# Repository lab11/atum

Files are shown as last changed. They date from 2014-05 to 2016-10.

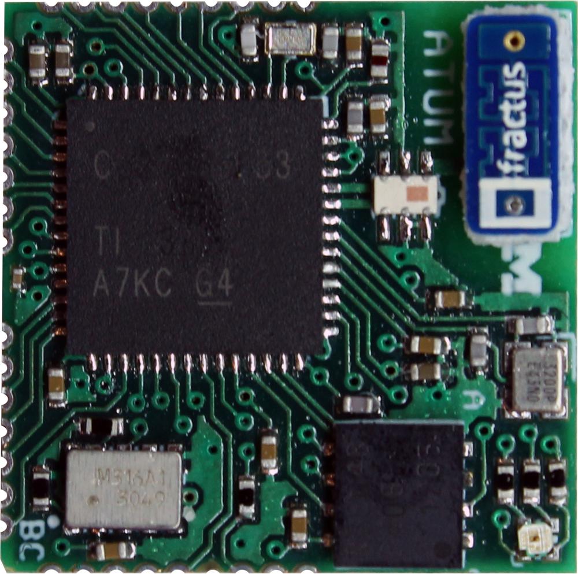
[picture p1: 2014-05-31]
hardware/atum/rev_a/atum.jpg

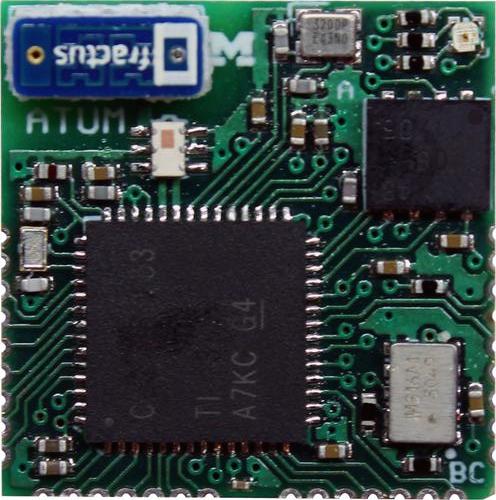
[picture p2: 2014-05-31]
media/atum_a_500x496.jpg

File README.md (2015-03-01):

Atum
====

atum_pcb

Atum is a ½ inch² drop-in sensor node module designed to enable rapid
prototyping of wireless embedded devices. The core of Atum is a CC2538
SoC with an Arm Cortex M3 and 802.15.4 radio. Atum also includes an
antenna, 512 bytes of non-volatile FRAM memory, an RTC, and a tri-color LED.

Atum is designed to have two different usage patterns. First, three sides
of the device have castellated headers allowing Atum to be directly
soldered onto a carrier PCB. Atum handles all of the computation and
communication while the carrier board supplies power and attaches
sensors or other peripherals. In the second option, Atum can function
as a complete sensor node. On the bottom are pads for a 3.3 V regulator
and a battery. If needed, a peripheral or sensor board can be stacked on
top using the headers as a bridge.

History
-------

Atum is the spiritual successor to
[Epic](http://www.cs.berkeley.edu/~prabal/projects/epic/). It is slightly
smaller, replaces flash with FRAM, adds an RTC, and includes an antenna.
Epic was designed to be highly flexible while still providing the
components that are common on many sensor platforms. In practice, however,
I noticed that only a small subset of the common features were regularly
used and that Epic carrier boards often repeated the same designs. Atum
tries to address this by providing a simplified interface that provides
the features (e.g. SPI, I2C, ADC, GPIO) that sensor boards need.

Name
----

The spelling "Atum" is taken from the ancient Egyptian god of creation,
but finds better connections as a misspelling of "atom", a core building
block of matter, and as the conjoined words "at" and "UM", as Atum
was developed at the University of Michigan.

Usage
-----

The [Contiki](https://github.com/contiki-os/contiki) operating system
supports the CC2538 and this repository contains a Contiki platform
for Atum. The Contiki platform provides drivers for the peripherals
on Atum and their wiring to the CC2538. See `CONTIKI.md` for more info.

PCB
---

Atum is currently pannelized 40 to a panel. They are designed to be 1mm thick
with castellations on the edge. See `hardware/atum` for board files and
gerbers.

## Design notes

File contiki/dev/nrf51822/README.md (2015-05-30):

Really basic support for the nRF51822 over spi
==============================================

This is a first pass at defining a SPI interface for the nRF51822 and accessing
it from Atum.

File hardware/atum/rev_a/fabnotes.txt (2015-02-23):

PCB NAME : ATUM
REVISION: A
DATE: 2015-02-23

PCB DESCRIPTION:4 LAYER PCB 1.0 MM
      Copper        1    1.4 mil (1 oz)
      Dielectric  1-2    5.7 mil (e.g. 2x Prepreg 1080)
      Copper        2    1.4 mil (1 oz)
      Dielectric  2-3   22.0 mil
      Copper        3    1.4 mil (1 oz)
      Dielectric  3-4    5.7 mil (e.g. 2x Prepreg 1080)
      Copper        4    1.4 mil (1 oz)
  DE104iML or equivalent substrate (Resin contents around 45%, which gives Er=4.42@2.4GHz, TanD=0.016)
  Dimensions in mil (0.001 inch)
  DOUBLE SIDE SOLDER MASK,
  DOUBLE SIDE SILKSCREEN,
  6 MIL MIN TRACE WIDTH AND 6 MIL MIN ISOLATION.

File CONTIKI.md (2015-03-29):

Programming Atum
================

The software for Atum is currently based on the Contiki support for
the TI CC2538. Getting running is pretty straightforward.

1. You need the `arm-none-gnueabi-gcc` compiler from
[here](https://launchpad.net/gcc-arm-embedded).

2. Clone Contiki recursively.

        git clone --recursive https://github.com/contiki-os/contiki.git

    Cloning recursively also pulls in the BSL programming script that loads
    code on the CC2538.

3. Now you should be able to build the blink app.

        cd contiki/apps/blink
        make

    You need to make sure that `CONTIKI` in the Makefile points to where
    you cloned the Contiki repository.

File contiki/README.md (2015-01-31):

Atum - Contiki
==============

This folder contains code to make Atum a
[Contiki](https://github.com/contiki-os/contiki) platform. Contiki has active
support of the CC2538 and this platform adds on drivers for the FRAM and
RTC chips.

Installation
------------

To compile apps for Atum you need this repository, the main Contiki repository,
and the toolchain.

1. Install the compilers. See
[this](https://github.com/contiki-os/contiki/tree/master/platform/cc2538dk#install-a-toolchain)
for a link to the best compiler to use for the CC2538.
Note: You MUST install from the launchpad website, NOT mentor.

2. Clone the main contiki repository

        git clone https://github.com/contiki-os/contiki.git

3. Add the `/tools` directory in this folder to your path. This folder contains
a script for initializing the RTC with the current time. Something like:

        export PATH=$PATH:$HOME/git/atum/contiki/tools

4. Make sure the applications know where the main Contiki repository is.
Edit `apps/blink/Makefile` and make sure that `CONTIKI = ../../../../contiki`
actually points to where you cloned the Contiki repository.

Compiling an Application
------------------------

At this point compiling a Contiki application for atum
should be very straightforward.

    cd apps/blink
    make

If you wanted to use a different platform (say the CC2538 evm with the SmartRF06
board):

    make TARGET=cc2538dk

Loading the Application to Atum
-------------------------------

Assuming you are using the serial bootloader (pins GND, VCC, !RESET,
BOOTLOADER_CTRL, BOOTLOADER_TX, and BOOTLOADER_RX) you can use the wonderful
[BSL script from JelmerT](https://github.com/JelmerT/cc2538-bsl) by:

    make install

In the case of a permission error for /dev/ttyUSB0, add yourself to the dialout
group.

Errors
------

It's possible these steps will not work. A major reason why is that the CC2538
platform in Contiki is changing rapidly and often adds in new features that
won't compile until the Atum platform is similarly updated. If this happens,
please raise an issue on this repository so that I can fix it.

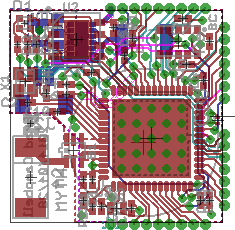
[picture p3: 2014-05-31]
hardware/atum/rev_a/myth_pcb.png

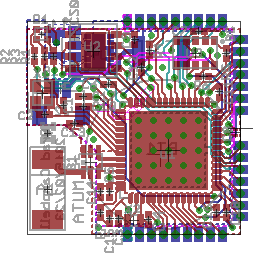
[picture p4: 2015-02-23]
hardware/atum/rev_a/atum_pcb.png

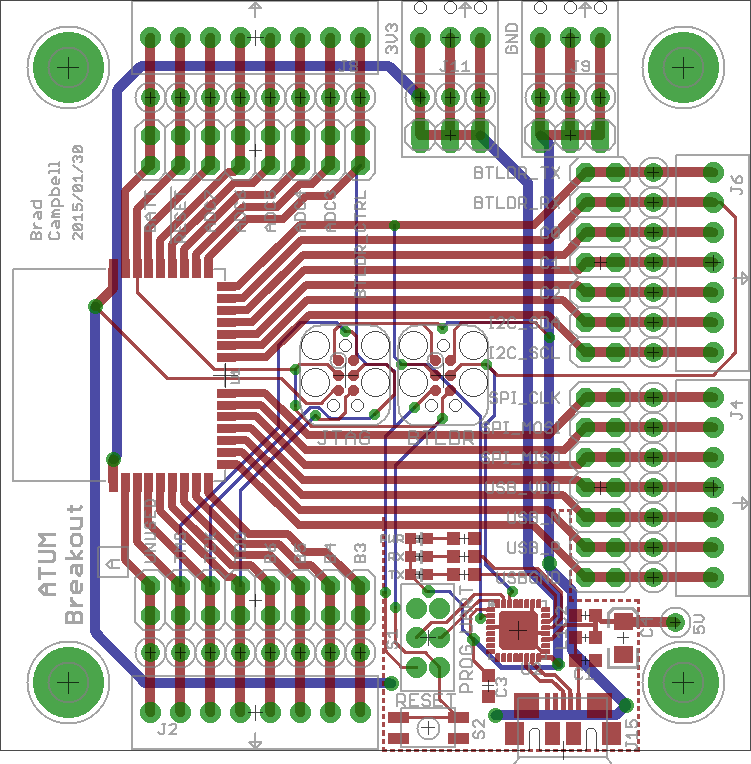
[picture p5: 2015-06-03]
hardware/atum-breakout/rev_a/atum-breakout_pcb.png

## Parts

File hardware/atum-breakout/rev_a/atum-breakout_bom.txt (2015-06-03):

# Bill of Materials
# Converted from atum-breakout_bom.xlsx
# Generated by bom_to_text.py

Qty  Value                          Device                         Package                        Parts                                                               Description                           DIGIKEY        MOUSER              NEWARK
3    0.1u                           C-EUC0603                      C0603                          C1, C2, C3                                                          CAPACITOR, European symbol            445-1316-1-ND  810-C1608X7R1E104K  
1    10u                            CAP_POL1206                    EIA3216                        C4                                                                  Capacitor Polarized                   478-1655-1-ND  581-TAJA106K016R    
1    BLUE                           LED0603                        LED-0603                       D1                                                                  LEDs                                                                     
1    RED                            LED0603                        LED-0603                       D2                                                                  LEDs                                                                     
1    GREEN                          LED0603                        LED-0603                       D3                                                                  LEDs                                                                     
2                                   PINHD-2X8                      2X08                           J1, J7                                                              PIN HEADER                            609-3364-ND    649-68602-116HLF    20M2833
2    SCREW-TERMINAL_8_0.100         SCREW-TERMINAL_8_0.100         CONN_BLOCK_8                   J2, J8                                                              8x 0.100 in screw terminal block      277-1279-ND    651-1725711         71C4111
2                                   PINHD-2X7                      2X07                           J3, J5                                                              PIN HEADER                            609-3491-ND    649-67996-114HLF    30M1973
2    SCREW-TERMINAL_7_0.100         SCREW-TERMINAL_7_0.100         CONN_BLOCK_7                   J4, J6                                                              7x 0.100 in screw terminal block      277-1278-ND    651-1725708         14X4980
2    SCREW-TERMINAL_3_0.100         SCREW-TERMINAL_3_0.100         CONN_BLOCK_3                   J9, J11                                                             3x 0.100 in screw terminal block      277-1274-ND    651-1725669         71C4108
2                                   PINHD-1X3                      1X03                           J10, J12                                                            PIN HEADER                            609-3461-ND    649-68000-103HLF    88K1775
1    MICRO_USB_B_HIROSE_ZX62R-B-5P  MICRO_USB_B_HIROSE_ZX62R-B-5P  USB_MICRO_B-HIROSE-ZX62R-B-5P  J15                                                                 USB Micro B Connector                 H11574CT-ND    798-ZX62R-B-5P      69W0714
1                                   INDUCTOR0603                   L0603                          L1                                                                  Inductors                             240-2373-1-ND  875-MI0603K300R-10  
3    470                            R-US_R0603                     R0603                          R1, R2, R3                                                          RESISTOR, American symbol                                                
1    SSA22/DPDT                     SSA22/DPDT                     SSA22/DPDT                     S1                                                                  SW SLIDE DPDT 2POS SSA SER 30V        450-1604-ND    506-SSA22           50F5561
1    EVQP2                          EVQP2                          EVQP2                          S2                                                                                                        P11084SCT-ND   667-EVQ-P2K02Q      
3    White                          TEST_POINT_0.040IN             TESTPOINT_0.040IN              TP1, TP29, TP30                                                     0.040in Test Point                    5002K-ND       534-5001            
10   Orange                         TEST_POINT_0.040IN             TESTPOINT_0.040IN              TP2, TP3, TP4, TP9, TP10, TP11, TP12, TP21, TP22, TP23              0.040in Test Point                    5003K-ND       534-5001            
12   Yellow                         TEST_POINT_0.040IN             TESTPOINT_0.040IN              TP5, TP6, TP7, TP8, TP18, TP19, TP20, TP24, TP25, TP26, TP27, TP28  0.040in Test Point                    5004K-ND       534-5001            
3    Blue                           TEST_POINT_0.040IN             TESTPOINT_0.040IN              TP13, TP14, TP15                                                    0.040in Test Point                    5117K-ND       534-5001            
2    Green                          TEST_POINT_0.040IN             TESTPOINT_0.040IN              TP16, TP17                                                          0.040in Test Point                    5116K-ND       534-5001            
3    Black                          TEST_POINT_0.040IN             TESTPOINT_0.040IN              TP31, TP32, TP33                                                    0.040in Test Point                    5001K-ND       534-5001            
4    Red                            TEST_POINT_0.040IN             TESTPOINT_0.040IN              TP34, TP35, TP36, TP37                                              0.040in Test Point                    5000K-ND       534-5001            
1    ATUM                           ATUM                           ATUM                           U1                                                                  Atum sensorboard prototyping module.                                     
1    FT232RQ                        FT232RQ                        QFN32                          U2                                                                  FTDI USB                              768-1008-1-ND  895-FT232RQ         91K9919

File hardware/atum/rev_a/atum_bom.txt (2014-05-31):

# Bill of Materials
# Converted from atum_bom.xlsx
# Generated by bom_to_text.py

Qty  Value                           Device                          Package                          Parts                             Description                                                   DIGIKEY           MOUSER               NEWARK   RICHARDSON_RFPD
1    FRACTUS-2.4GHZ-FR05-S1-N-0-102  FRACTUS-2.4GHZ-FR05-S1-N-0-102  FRACTUS-ANTENNA-FR05-S1-N-0-102  A1                                Fractus Compact Reach XtendTM chip antenna                                                                    FR05-S1-N-0102B
1    2450BM15A0002                   2450BM15A0002                   2450BM                           B1                                BALUN JTI MATCHED ZIGBEE                                      712-1536-1-ND     609-2450BM15A0002E   41T1684  
1    ML-1220/F1AN                    ML-1220/F1AN                    ML-1220/F1BN                     BT1                               BATTERY LITH 3V RECHARGE PC PINS                              P663-ND           658-ML-1220/F1BN              
2    12pF                            CAPACITOR                       0402_CAP                         C1, C2                            0402 Capacitor                                                445-1236-1-ND                          90R7560  
2    22pF                            CAPACITOR                       0402_CAP                         C3, C4                            0402 Capacitor                                                490-5868-1-ND                          48W5745  
1    220pF                           CAPACITOR                       0402_CAP                         C5                                0402 Capacitor                                                445-1251-1-ND                          55T0065  
1    1nF                             CAPACITOR                       0402_CAP                         C6                                0402 Capacitor                                                445-2651-1-ND                          90R7554  
1    10nF                            CAPACITOR                       0402_CAP                         C7                                0402 Capacitor                                                445-1260-1-ND                          90R7604  
1    0.1uF                           C-EUC0201                       0201_CAP                         C8                                0201 Capacitor                                                445-1796-1-ND                          90R7553  
7    0.1uF                           CAPACITOR                       0402_CAP                         C9, C10, C11, C12, C13, C14, C15  0402 Capacitor                                                445-1265-1-ND                          87R3259  
3    1uF                             CAPACITOR                       0402_CAP                         C16, C17, C18                     0402 Capacitor                                                445-4998-1-ND                          90R7580  
2    10uF                            CAPACITOR0603_CAP               0603_CAP                         C19, C20                          CAP CER 10UF 6.3V 20% X5R 0603                                490-7316-1-ND                                   
1    SML-LX0404SIUPGUSB              SML-LX0404SIUPGUSB              1MM_SQ_4PAD                      D1                                1mm^2 RGB LED                                                 67-2125-1-ND      696-LX0404SIUPGUSB   23T0583  
1    ATUM-HEADER                     ATUM-HEADER                     ATUM-HEADER                      J1                                                                                                                                              
1    SH_MALE_2/1MM                   SH_MALE_2/1MM                   SH-1X2/1MM                       J2                                1.0mm pitch/Disconnectable Crimp style connectors             455-1788-2-ND                          26P0950  
1    2.2uH                           MIPSZ2012D                      MIPSZ201D                        L1                                FDK Multi-layer Power Inductor (Very Small Type)                                                              
3    1k                              RESISTOR                        0402_RES                         R1, R2, R3                        Resistor                                                      RHM1.0KCECT-ND                                  
1    2.2k                            RESISTOR                        0402_RES                         R4                                Resistor                                                      RHM2.2KCECT-ND                                  
2    10k                             RESISTOR                        0402_RES                         R5, R6                            Resistor                                                      RHM10KCECT-ND                                   
1    56k                             RESISTOR                        0402_RES                         R7                                Resistor                                                      RHM56KBHCT-ND                                   
1    CC2538                          CC2538                          S-PVQFN-N56                      U1                                A Powerful System-On-Chip for 2.4-GHz IEEE 802.15.4, 6LoWPAN  296-35797-1-ND    595-CC2538SF53RTQT   87W7713  
1    FM25LBTDFN-8                    FM25LBTDFN-8                    TDFN-8                           U2                                IC FRAM 4KBIT 10MHZ 8SOIC                                     FM25L04B-DGRA-ND  877-FM25L04B-DG               
1    RV-3049-C3                      RV-3049-C3                      MICRO-CRYSTAL-C3                 U3                                Ultra miniature Real-Time-Clock Module                                                               09X0513  
1    TPS62740                        TPS62740                        R-PWSON-12                       U4                                360nA Step Down Converter for Low Power Applications          296-37134-1-ND    595-TPS62740DSST     27X9745  
1    EPSON-FA-128                    EPSON-FA-128                    FA-128                           X1                                MHz RANGE CRYSTAL UNIT                                        SER3800CT-ND      732-FA128-32F20X-K3           
1    ABS05-32.768KHZ-T               ABS05-32.768KHZ-T               ABS05                            X2                                32.768kHz Crystal                                             535-11899-1-ND    815-ABS05-32.768K-T  24W8430

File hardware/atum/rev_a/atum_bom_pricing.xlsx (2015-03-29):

Qty | Value | Device | Package | Parts | Description | DIGIKEY | MOUSER | NEWARK | RICHARDSON_RFPD | Price@Qty1000 | Total@1000
1 | FRACTUS-2.4GHZ-FR05-S1-N-0-102 | FRACTUS-2.4GHZ-FR05-S1-N-0-102 | FRACTUS-ANTENNA-FR05-S1-N-0-102 | A1 | Fractus Compact Reach XtendTM chip antenna |  |  |  | FR05-S1-N-0102B | 0.68 | 680
1 | 2450BM15A0002 | 2450BM15A0002 | 2450BM | B1 | BALUN JTI MATCHED ZIGBEE | 712-1536-1-ND | 609-2450BM15A0002E | 41T1684 |  | 0.2875 | 287.5
1 | ML-1220/F1AN | ML-1220/F1AN | ML-1220/F1BN | BT1 | BATTERY LITH 3V RECHARGE PC PINS | P663-ND | 658-ML-1220/F1BN |  |  |  | 0
2 | 12pF | CAPACITOR | 0402_CAP | C1, C2 | 0402 Capacitor | 445-1236-1-ND |  | 90R7560 |  | 0.013 | 26
2 | 22pF | CAPACITOR | 0402_CAP | C3, C4 | 0402 Capacitor | 490-5868-1-ND |  | 48W5745 |  | 0.01024 | 10.24
1 | 220pF | CAPACITOR | 0402_CAP | C5 | 0402 Capacitor | 445-1251-1-ND |  | 55T0065 |  | 0.0151 | 15.1
1 | 1nF | CAPACITOR | 0402_CAP | C6 | 0402 Capacitor | 445-2651-1-ND |  | 90R7554 |  | 0.0345 | 34.5
1 | 10nF | CAPACITOR | 0402_CAP | C7 | 0402 Capacitor | 445-1260-1-ND |  | 90R7604 |  | 0.013 | 13
1 | 0.1uF | C-EUC0201 | 0201_CAP | C8 | 0201 Capacitor | 445-1796-1-ND |  | 90R7553 |  | 0.0151 | 105.7
7 | 0.1uF | CAPACITOR | 0402_CAP | C9, C10, C11, C12, C13, C14, C15 | 0402 Capacitor | 445-1265-1-ND |  | 87R3259 |  | 0.0133 | 39.9
3 | 1uF | CAPACITOR | 0402_CAP | C16, C17, C18 | 0402 Capacitor | 445-4998-1-ND |  | 90R7580 |  | 0.0169 | 33.8
2 | 10uF | CAPACITOR0603_CAP | 0603_CAP | C19, C20 | CAP CER 10UF 6.3V 20% X5R 0603 | 490-7316-1-ND |  |  |  |  | 0
1 | SML-LX0404SIUPGUSB | SML-LX0404SIUPGUSB | 1MM_SQ_4PAD | D1 | 1mm^2 RGB LED | 67-2125-1-ND | 696-LX0404SIUPGUSB | 23T0583 |  | 0.406 | 406
1 | ATUM-HEADER | ATUM-HEADER | ATUM-HEADER | J1 |  |  |  |  |  |  | 0
1 | SH_MALE_2/1MM | SH_MALE_2/1MM | SH-1X2/1MM | J2 | 1.0mm pitch/Disconnectable Crimp style connectors | 455-1788-2-ND |  | 26P0950 |  |  | 0
1 | 2.2uH | MIPSZ2012D | MIPSZ201D | L1 | FDK Multi-layer Power Inductor (Very Small Type) |  |  |  |  |  | 0
3 | 1k | RESISTOR | 0402_RES | R1, R2, R3 | Resistor | RHM1.0KCECT-ND |  |  |  | 0.00933 | 9.33
1 | 2.2k | RESISTOR | 0402_RES | R4 | Resistor | RHM2.2KCECT-ND |  |  |  | 0.02031 | 40.62
2 | 10k | RESISTOR | 0402_RES | R5, R6 | Resistor | RHM10KCECT-ND |  |  |  | 0.02031 | 20.31
1 | 56k | RESISTOR | 0402_RES | R7 | Resistor | RHM56KBHCT-ND |  |  |  | 0.02684 | 26.84
1 | CC2538 | CC2538 | S-PVQFN-N56 | U1 | A Powerful System-On-Chip for 2.4-GHz IEEE 802.15.4, 6LoWPAN | 296-35797-1-ND | 595-CC2538SF53RTQT | 87W7713 |  | 6.6924 | 6692.4
1 | FM25LBTDFN-8 | FM25LBTDFN-8 | TDFN-8 | U2 | IC FRAM 4KBIT 10MHZ 8SOIC | FM25L04B-DGRA-ND | 877-FM25L04B-DG |  |  | 1.053 | 1053
1 | RV-3049-C3 | RV-3049-C3 | MICRO-CRYSTAL-C3 | U3 | Ultra miniature Real-Time-Clock Module |  |  | 09X0513 |  | 8.42 | 8420
1 | TPS62740 | TPS62740 | R-PWSON-12 | U4 | 360nA Step Down Converter for Low Power Applications | 296-37134-1-ND | 595-TPS62740DSST | 27X9745 |  |  | 0
1 | EPSON-FA-128 | EPSON-FA-128 | FA-128 | X1 | MHz RANGE CRYSTAL UNIT | SER3800CT-ND | 732-FA128-32F20X-K3 |  |  | 0.6 | 600
1 | ABS05-32.768KHZ-T | ABS05-32.768KHZ-T | ABS05 | X2 | 32.768kHz Crystal | 535-11899-1-ND | 815-ABS05-32.768K-T | 24W8430 |  | 1.061 | 0
 |  |  |  |  | PCB |  |  |  |  | 1.5 | 1500
 |  |  |  |  | Assembly |  |  |  |  | 5 | 5000
 |  |  |  |  |  |  |  |  |  |  | 25014.24
 |  |  |  |  |  |  |  |  |  |  | 25.01424

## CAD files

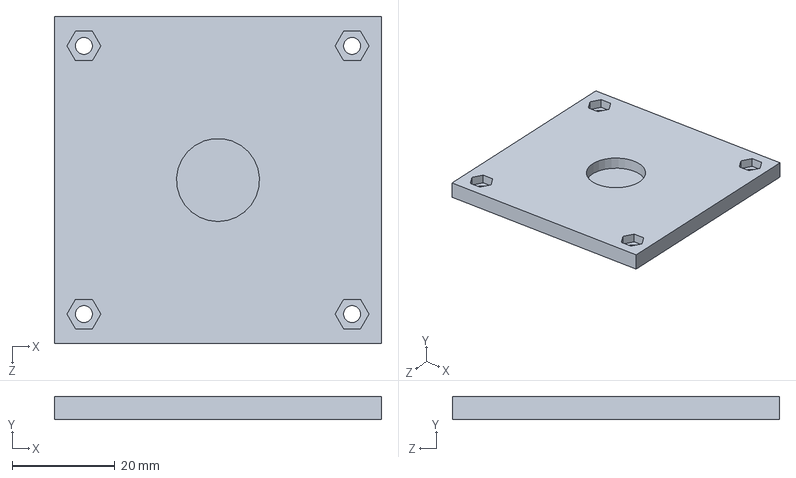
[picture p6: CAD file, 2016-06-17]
3d/atum_breakout_magnet_base.SLDPRT
63.5 x 4.48 x 63.5 mm

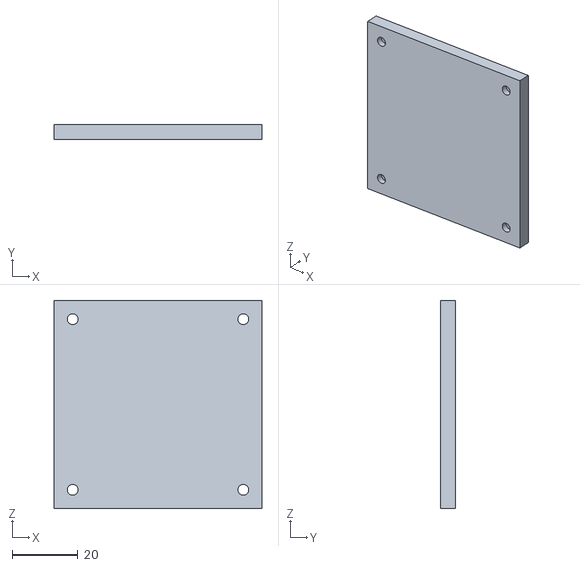
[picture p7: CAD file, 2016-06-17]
3d/atum_breakout_magnet_base_v1.STL
63.5 x 4.48 x 63.5

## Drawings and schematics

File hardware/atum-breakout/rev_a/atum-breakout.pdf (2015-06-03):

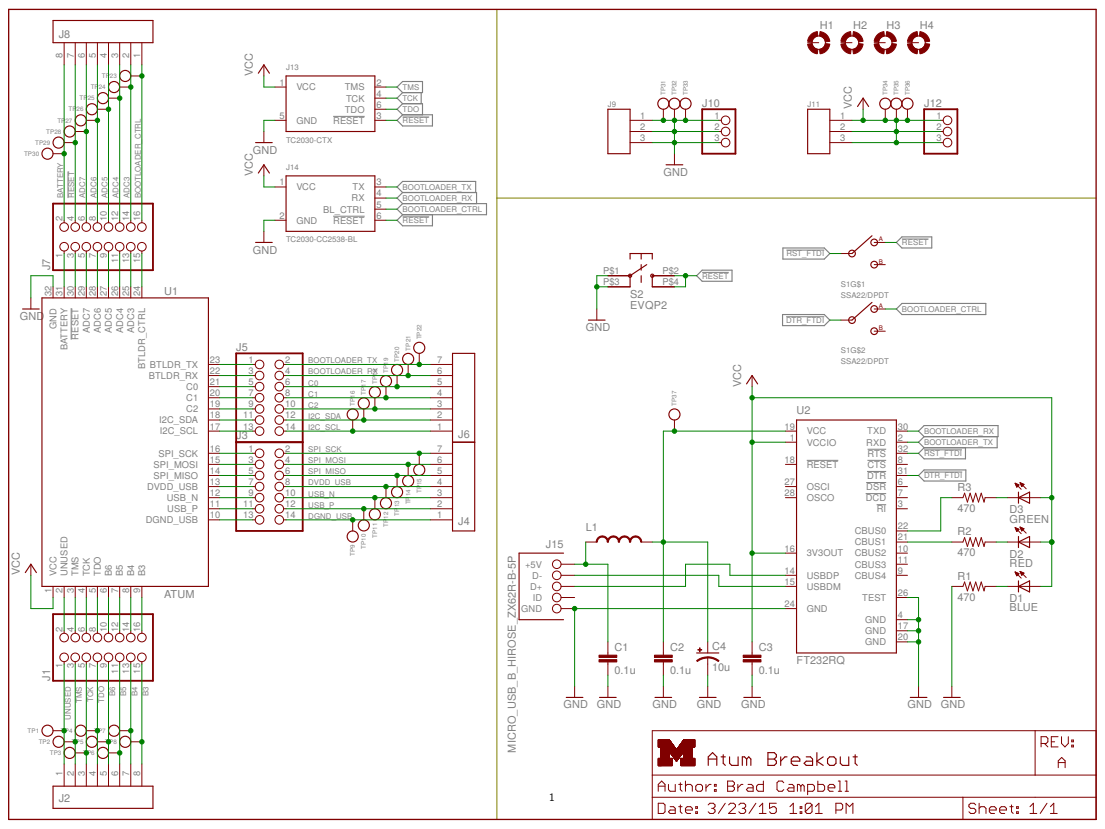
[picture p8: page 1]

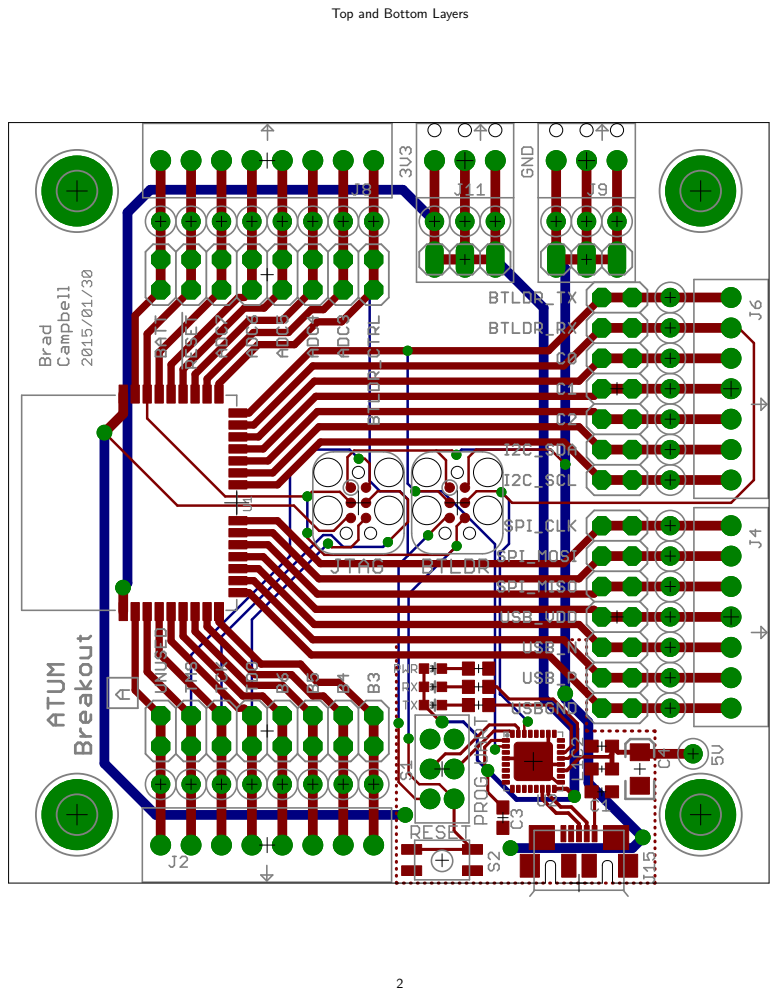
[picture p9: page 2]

Top and Bottom Layers

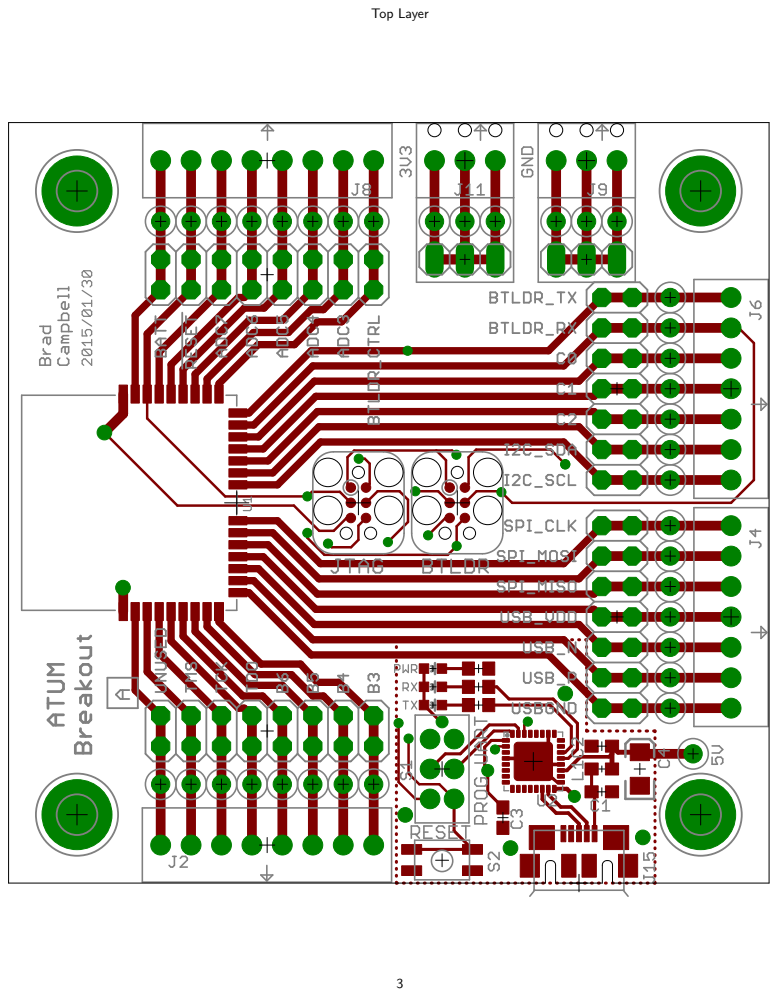
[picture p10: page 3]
Top Layer

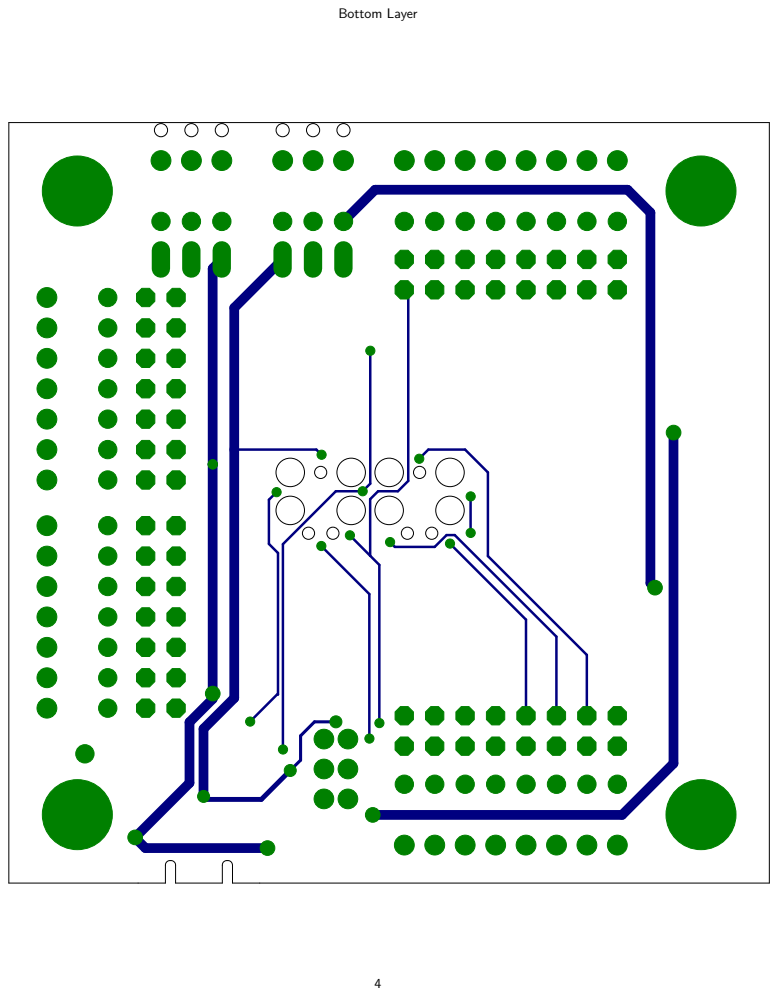
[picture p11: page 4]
Bottom Layer

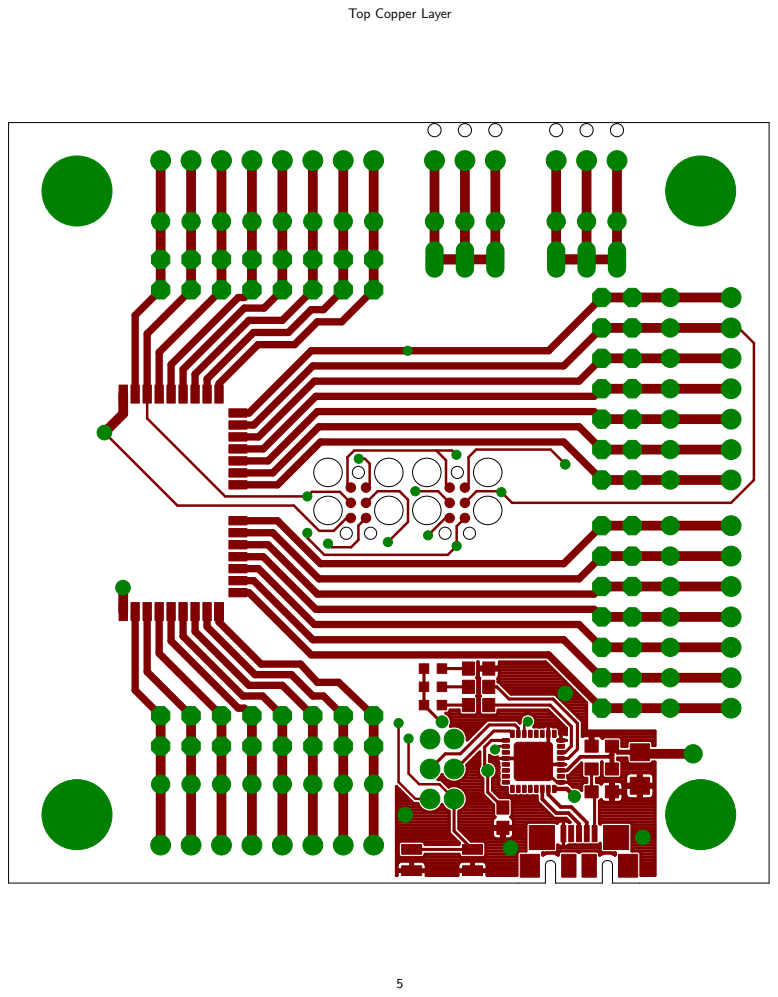
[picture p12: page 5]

Top Copper Layer

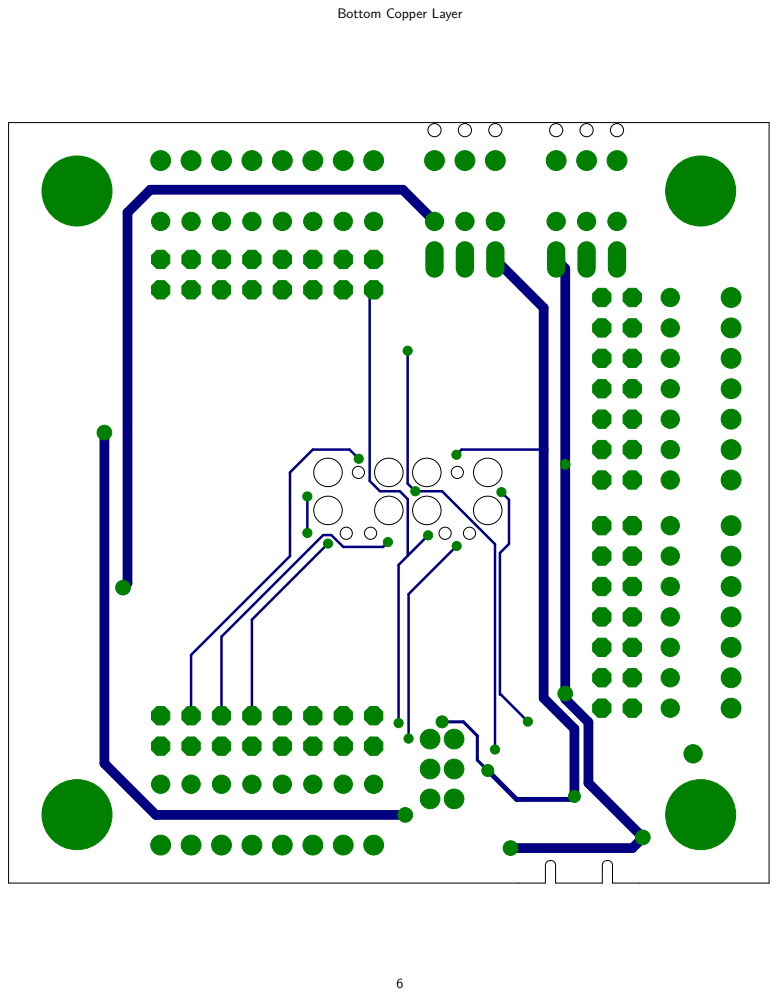
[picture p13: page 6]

Bottom Copper Layer

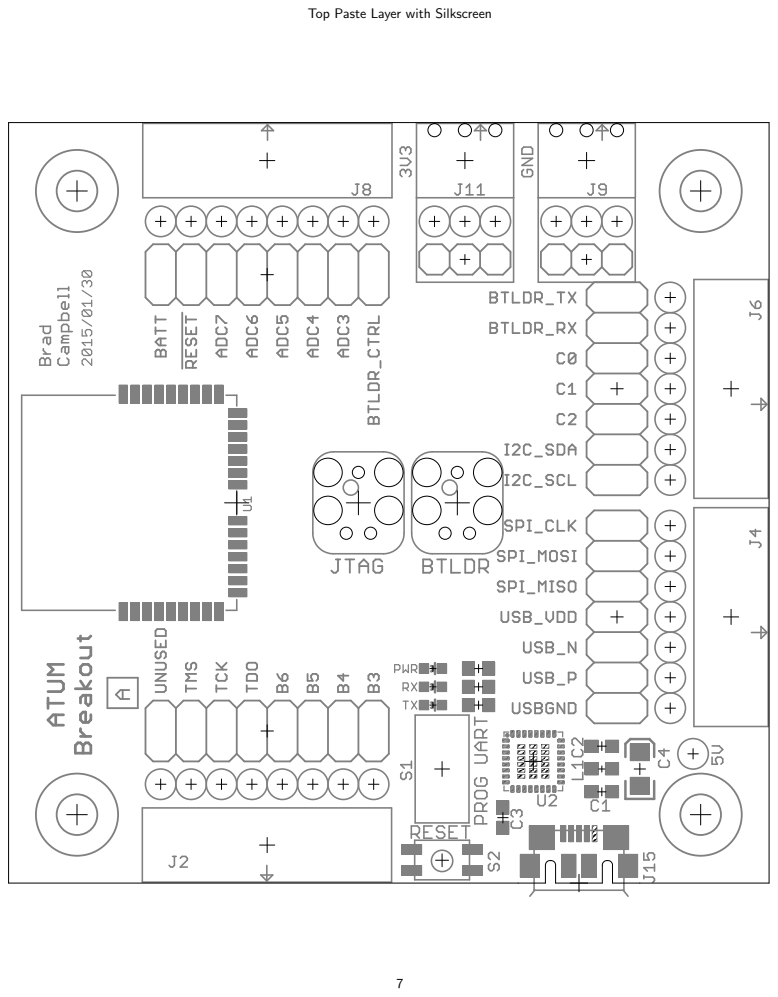
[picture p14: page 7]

Top Paste Layer with Silkscreen

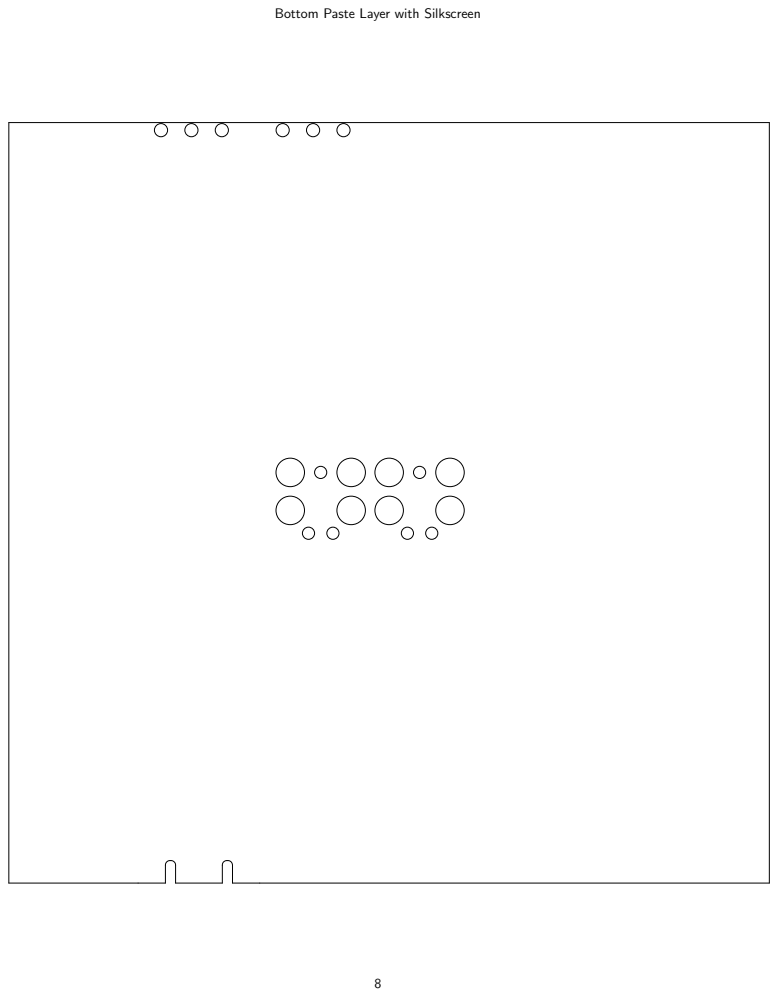
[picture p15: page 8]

Bottom Paste Layer with Silkscreen

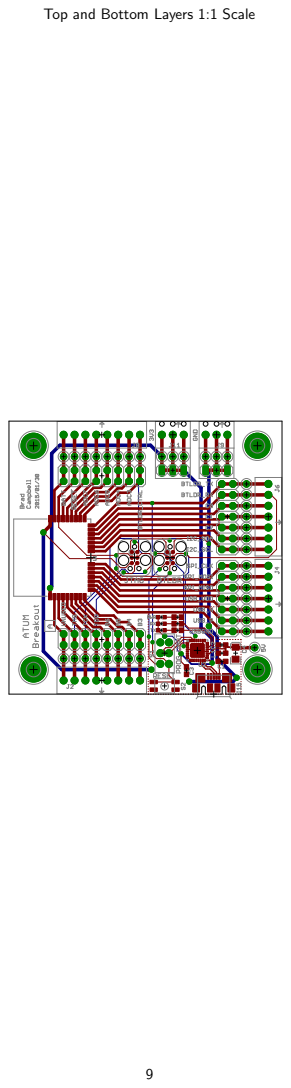
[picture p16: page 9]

Top and Bottom Layers 1:1 Scale

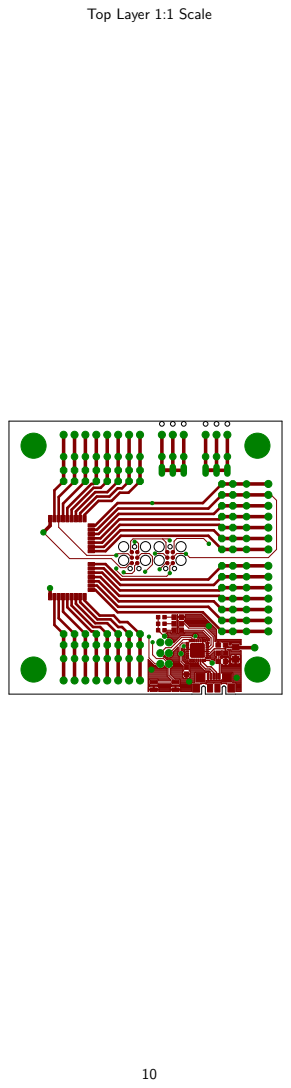
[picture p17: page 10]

Top Layer 1:1 Scale

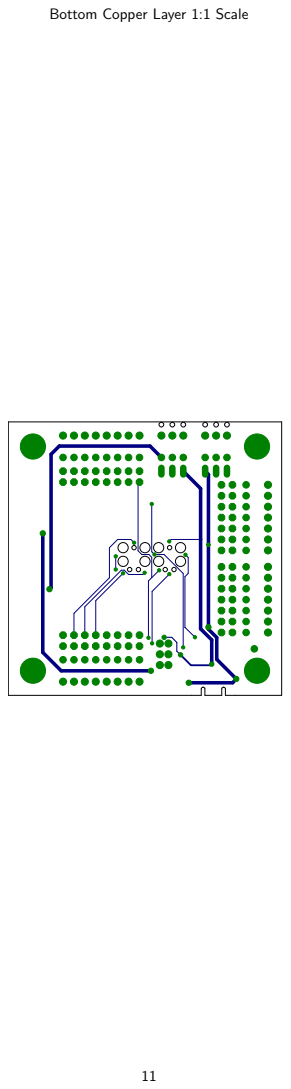
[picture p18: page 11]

Bottom Copper Layer 1:1 Scale

### Sheet1

Qty Value | Device
3 0.1u | C-EUC0603
1 10u | CAP_POL1206
1 BLUE | LED0603
1 RED | LED0603
1 GREEN | LED0603
2 | PINHD-2X8
2 SCREW-TERMINAL_8_0.100 | SCREW-TERMINAL_8_0.100
2 | PINHD-2X7
2 SCREW-TERMINAL_7_0.100 | SCREW-TERMINAL_7_0.100
2 SCREW-TERMINAL_3_0.100 | SCREW-TERMINAL_3_0.100
2 | PINHD-1X3
1 MICRO_USB_B_HIROSE_ZX62R-B-5P MICRO_USB_B_HIROSE_ZX62R-B-5P
1 | INDUCTOR0603
3 470 | R-US_R0603
1 SSA22/DPDT | SSA22/DPDT
1 EVQP2 | EVQP2
3 White | TEST_POINT_0.040IN
10 Orange | TEST_POINT_0.040IN
12 Yellow | TEST_POINT_0.040IN
3 Blue | TEST_POINT_0.040IN
2 Green | TEST_POINT_0.040IN
3 Black | TEST_POINT_0.040IN
4 Red | TEST_POINT_0.040IN
1 ATUM | ATUM
1 FT232RQ | FT232RQ

### Sheet1

Package
C0603
EIA3216
LED-0603
LED-0603
LED-0603
2X08
CONN_BLOCK_8
2X07
CONN_BLOCK_7
CONN_BLOCK_3
1X03
USB_MICRO_B-HIROSE-ZX62R-B-5P L0603
R0603
SSA22/DPDT
EVQP2
TESTPOINT_0.040IN
TESTPOINT_0.040IN
TESTPOINT_0.040IN
TESTPOINT_0.040IN
TESTPOINT_0.040IN
TESTPOINT_0.040IN
TESTPOINT_0.040IN
ATUM
QFN32

### Sheet1

Parts
C1, C2, C3
C4
D1
D2
D3
J1, J7
J2, J8
J3, J5
J4, J6
J9, J11
J10, J12
J15
L1
R1, R2, R3
S1
S2
TP1, TP29, TP30
TP2, TP3, TP4, TP9, TP10, TP11, TP12, TP21, TP22, TP23
TP5, TP6, TP7, TP8, TP18, TP19, TP20, TP24, TP25, TP26, TP27, TP28 TP13, TP14, TP15
TP16, TP17
TP31, TP32, TP33
TP34, TP35, TP36, TP37
U1
U2

### Sheet1

Description | DIGIKEY | MOUSER | NEWARK
CAPACITOR, European symbol | 445-1316-1-ND | 810-C1608X7R1E104K
Capacitor Polarized | 478-1655-1-ND | 581-TAJA106K016R
LEDs
LEDs
LEDs
PIN HEADER | 609-3364-ND | 649-68602-116HLF | 20M2833
8x 0.100 in screw terminal block | 277-1279-ND | 651-1725711 | 71C4111
PIN HEADER | 609-3491-ND | 649-67996-114HLF | 30M1973
7x 0.100 in screw terminal block | 277-1278-ND | 651-1725708 | 14X4980
3x 0.100 in screw terminal block | 277-1274-ND | 651-1725669 | 71C4108
PIN HEADER | 609-3461-ND | 649-68000-103HLF | 88K1775
USB Micro B Connector | H11574CT-ND | 798-ZX62R-B-5P | 69W0714
Inductors | 240-2373-1-ND | 875-MI0603K300R-10
RESISTOR, American symbol
SW SLIDE DPDT 2POS SSA SER 30V | 450-1604-ND | 506-SSA22 | 50F5561
P11084SCT-ND 667-EVQ-P2K02Q
0.040in Test Point | 5002K-ND | 534-5001
0.040in Test Point | 5003K-ND | 534-5001
0.040in Test Point | 5004K-ND | 534-5001
0.040in Test Point | 5117K-ND | 534-5001
0.040in Test Point | 5116K-ND | 534-5001
0.040in Test Point | 5001K-ND | 534-5001
0.040in Test Point | 5000K-ND | 534-5001
Atum sensorboard prototyping module.
FTDI USB | 768-1008-1-ND | 895-FT232RQ | 91K9919

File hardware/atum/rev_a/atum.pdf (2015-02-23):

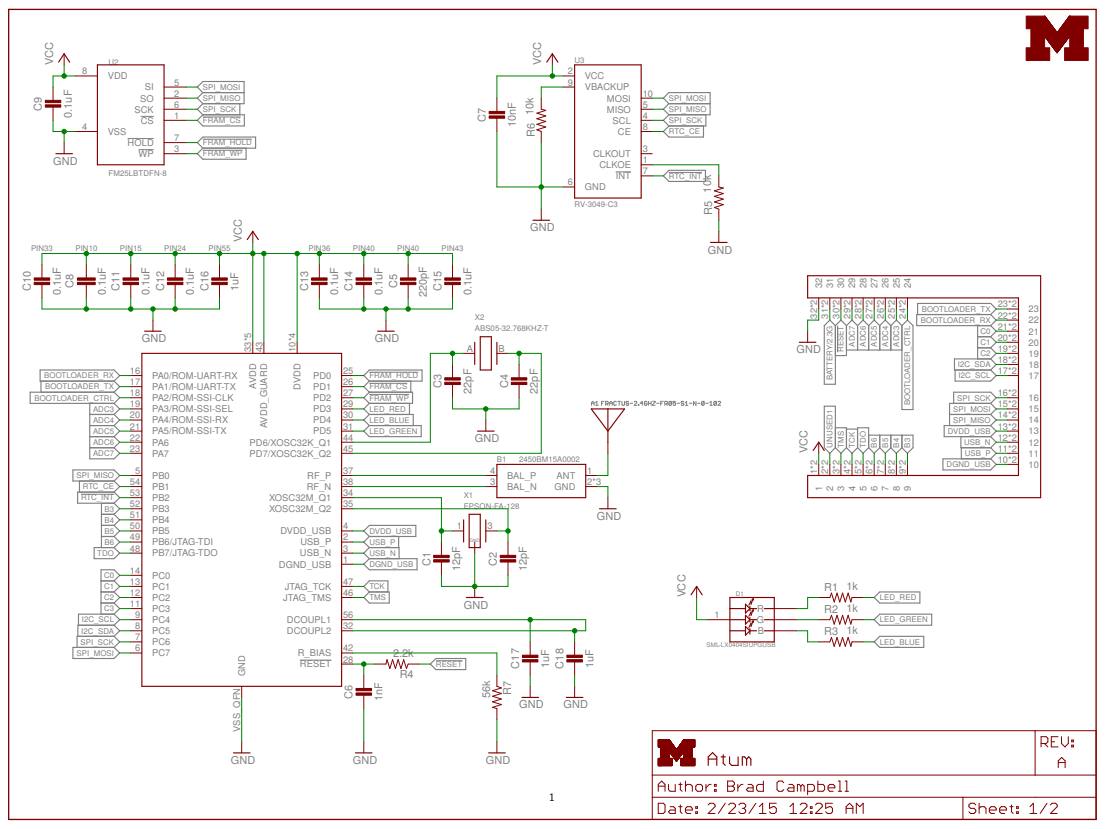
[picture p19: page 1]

32
42

2 2.8V Output TPS62740 GND; GND 2.2; VCC; ML-1220/F1AN GND ¹⁰uF; SH_MALE_2/1MM GND SW VOUT PG CTRL GND; LOAD VSEL4 VSEL3 VSEL2 VSEL1 ENVIN U4; +- BT1 C¹⁹; C²⁰; J2 ¹² BATTERY/1.10G; BATTERY/1.10G BATTERY/1.10G


Top and Bottom Layers

Top Layer

Bottom Layer


Top Copper Layer

Layer 2 Copper

Layer 3 Copper


Bottom Copper Layer


Top Paste Layer with Silkscreen

Bottom Paste Layer with Silkscreen


Top and Bottom Layers 1:1 Scale

Top Layer 1:1 Scale

Layer 2 Copper 1:1 Scale

Layer 3 Copper 1:1 Scale


Bottom Copper Layer 1:1 Scale

### Sheet1

Qty Value | Device
1 FRACTUS-2.4GHZ-FR05-S1-N-0-102 FRACTUS-2.4GHZ-FR05-S1-N-0-102
1 2450BM15A0002 | 2450BM15A0002
1 ML-1220/F1AN | ML-1220/F1AN
2 12pF | CAPACITOR
2 22pF | CAPACITOR
1 220pF | CAPACITOR
1 1nF | CAPACITOR
1 10nF | CAPACITOR
1 0.1uF | C-EUC0201
7 0.1uF | CAPACITOR
3 1uF | CAPACITOR
2 10uF | CAPACITOR0603_CAP
1 SML-LX0404SIUPGUSB | SML-LX0404SIUPGUSB
1 ATUM-HEADER | ATUM-HEADER
1 SH_MALE_2/1MM | SH_MALE_2/1MM
1 2.2uH | MIPSZ2012D
3 1k | RESISTOR
1 2.2k | RESISTOR
2 10k | RESISTOR
1 56k | RESISTOR
1 CC2538 | CC2538
1 FM25LBTDFN-8 | FM25LBTDFN-8
1 RV-3049-C3 | RV-3049-C3
1 TPS62740 | TPS62740
1 EPSON-FA-128 | EPSON-FA-128
1 ABS05-32.768KHZ-T | ABS05-32.768KHZ-T

### Sheet1

Package | Parts
FRACTUS-ANTENNA-FR05-S1-N-0-102 A1
2450BM | B1
ML-1220/F1BN | BT1
0402_CAP | C1, C2
0402_CAP | C3, C4
0402_CAP | C5
0402_CAP | C6
0402_CAP | C7
0201_CAP | C8
0402_CAP | C9, C10, C11, C12, C13, C14, C15
0402_CAP | C16, C17, C18
0603_CAP | C19, C20
1MM_SQ_4PAD | D1
ATUM-HEADER | J1
SH-1X2/1MM | J2
MIPSZ201D | L1
0402_RES | R1, R2, R3
0402_RES | R4
0402_RES | R5, R6
0402_RES | R7
S-PVQFN-N56 | U1
TDFN-8 | U2
MICRO-CRYSTAL-C3 | U3
R-PWSON-12 | U4
FA-128 | X1
ABS05 | X2

### Sheet1

Description | DIGIKEY
Fractus Compact Reach XtendTM chip antenna
BALUN JTI MATCHED ZIGBEE | 712-1536-1-ND
BATTERY LITH 3V RECHARGE PC PINS | P663-ND
0402 Capacitor | 445-1236-1-ND
0402 Capacitor | 490-5868-1-ND
0402 Capacitor | 445-1251-1-ND
0402 Capacitor | 445-2651-1-ND
0402 Capacitor | 445-1260-1-ND
0201 Capacitor | 445-1796-1-ND
0402 Capacitor | 445-1265-1-ND
0402 Capacitor | 445-4998-1-ND
CAP CER 10UF 6.3V 20% X5R 0603 | 490-7316-1-ND
1mm^2 RGB LED | 67-2125-1-ND
1.0mm pitch/Disconnectable Crimp style connectors | 455-1788-2-ND
FDK Multi-layer Power Inductor (Very Small Type)
Resistor | RHM1.0KCECT-ND
Resistor | RHM2.2KCECT-ND
Resistor | RHM10KCECT-ND
Resistor | RHM56KBHCT-ND
A Powerful System-On-Chip for 2.4-GHz IEEE 802.15.4, 6LoWPAN 296-35797-1-ND
IC FRAM 4KBIT 10MHZ 8SOIC | FM25L04B-DGRA-ND
Ultra miniature Real-Time-Clock Module
360nA Step Down Converter for Low Power Applications | 296-37134-1-ND
MHz RANGE CRYSTAL UNIT | SER3800CT-ND
32.768kHz Crystal | 535-11899-1-ND

### Sheet1

MOUSER | NEWARK RICHARDSON_RFPD
| FR05-S1-N-0102B
609-2450BM15A0002E | 41T1684
658-ML-1220/F1BN
| 90R7560
| 48W5745
| 55T0065
| 90R7554
| 90R7604
| 90R7553
| 87R3259
| 90R7580

696-LX0404SIUPGUSB 23T0583

| 26P0950

595-CC2538SF53RTQT 87W7713 877-FM25L04B-DG
09X0513
595-TPS62740DSST 27X9745
732-FA128-32F20X-K3
815-ABS05-32.768K-T 24W8430

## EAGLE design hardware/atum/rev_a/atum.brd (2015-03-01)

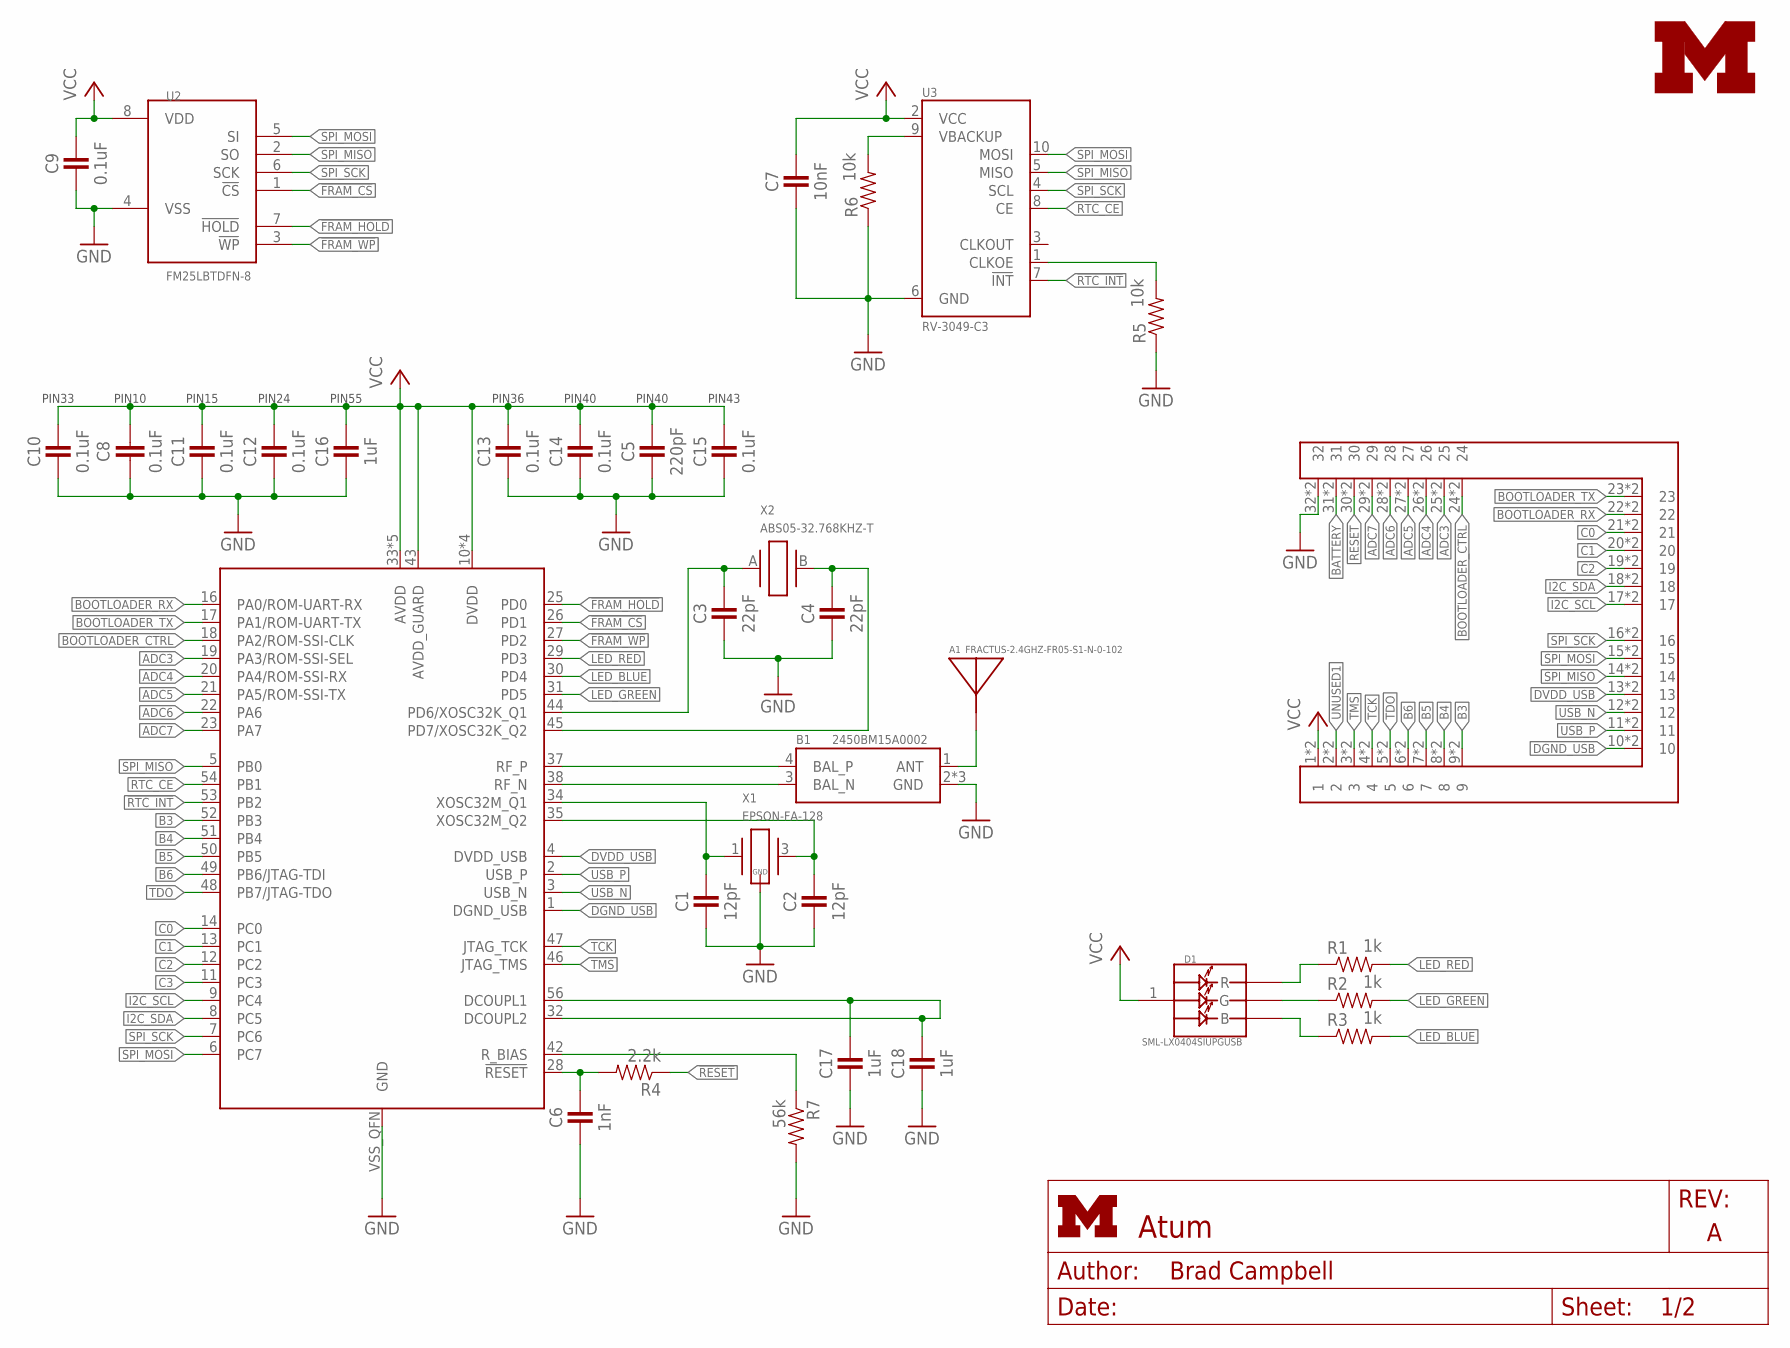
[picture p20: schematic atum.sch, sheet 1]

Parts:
A1: FRACTUS-2.4GHZ-FR05-S1-N-0-102; FRACTUS-ANTENNA-FR05-S1-N-0-102
B1: 2450BM15A0002; 2450BM
C1, C2: 12pF; 0402_CAP
C3, C4: 22pF; 0402_CAP
C5: 220pF; 0402_CAP
C6: 1nF; 0402_CAP
C7: 10nF; 0402_CAP
C8: 0.1uF; C0201
C9, C10, C11, C12, C13, C14, C15: 0.1uF; 0402_CAP
C16, C17, C18: 1uF; 0402_CAP
D1: SML-LX0404SIUPGUSB; 1MM_SQ_4PAD
J3: ATUM-HEADER
LOGO1: UMICH_SOLID_TINY; UMICH_SOLID_50MIL
R1, R2, R3: 1k; 0402_RES
R4: 2.2k; 0402_RES
R5, R6: 10k; 0402_RES
R7: 56k; 0402_RES
U1: CC2538; S-PVQFN-N56
U2: FM25LBTDFN-8; TDFN-8; DIGIKEY FM25L04B-DGRA-ND
U3: RV-3049-C3; MICRO-CRYSTAL-C3
X1: EPSON-FA-128; FA-128
X2: ABS05-32.768KHZ-T; ABS05

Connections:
!FRAM_CS: U1.26 (PD1), U2.1 (!CS)
!FRAM_HOLD: U1.25 (PD0), U2.7 (!HOLD)
!FRAM_WP: U1.27 (PD2), U2.3 (!WP)
!RESET: J3.30, J3.30B (30), R4.1
!RTC_INT: U1.53 (PB2), U3.7 (!INT)
ADC3: J3.25, J3.25B (25), U1.19 (PA3/ROM-SSI-SEL)
ADC4: J3.26, J3.26B (26), U1.20 (PA4/ROM-SSI-RX)
ADC5: J3.27, J3.27B (27), U1.21 (PA5/ROM-SSI-TX)
ADC6: J3.28, J3.28B (28), U1.22 (PA6)
ADC7: J3.29, J3.29B (29), U1.23 (PA7)
ANTENNA: A1.1, B1.1 (ANT)
B3: J3.9, J3.9B (9), U1.52 (PB3)
B4: J3.8, J3.8B (8), U1.51 (PB4)
B5: J3.7, J3.7B (7), U1.50 (PB5)
B6: J3.6, J3.6B (6), U1.49 (PB6/JTAG-TDI)
BATTERY: J3.31, J3.31B (31); also elsewhere on the board
BOOTLOADER_CTRL: J3.24, J3.24B (24), U1.18 (PA2/ROM-SSI-CLK)
BOOTLOADER_RX: J3.22, J3.22B (22), U1.16 (PA0/ROM-UART-RX)
BOOTLOADER_TX: J3.23, J3.23B (23), U1.17 (PA1/ROM-UART-TX)
C0: J3.21, J3.21B (21), U1.14 (PC0)
C1: J3.20, J3.20B (20), U1.13 (PC1)
C2: J3.19, J3.19B (19), U1.12 (PC2)
C3: U1.11 (PC3)
DGND_USB: J3.10, J3.10B (10), U1.1 (DGND_USB)
DVDD_USB: J3.13, J3.13B (13), U1.4 (DVDD_USB)
GND: B1.2 (GND), B1.5 (GND), B1.6 (GND), C1.2, C2.2, C3.2, C4.2, C5.2, C6.2, C7.2, C8.2, C9.2, C10.2, C11.2, C12.2, C13.2, C14.2, C15.2, C16.2, C17.2, C18.2, J3.32, J3.32B (32), R5.1, R6.1, R7.2, U1.VSS_QFN (GND), U2.4 (VSS), U3.6 (GND), X1.2 (GND), X1.4 (GND); also elsewhere on the board
I2C_SCL: J3.17, J3.17B (17), U1.9 (PC4)
I2C_SDA: J3.18, J3.18B (18), U1.8 (PC5)
LED_BLUE: R3.2, U1.30 (PD4)
LED_GREEN: R2.2, U1.31 (PD5)
LED_RED: R1.2, U1.29 (PD3)
unnamed: C6.1, R4.2, U1.28 (!RESET)
unnamed: C3.1, U1.44 (PD6/XOSC32K_Q1), X2.A (1)
unnamed: D1.2 (R), R1.1
unnamed: R7.1, U1.42 (R_BIAS)
unnamed: C1.1, U1.34 (XOSC32M_Q1), X1.1
unnamed: C2.1, U1.35 (XOSC32M_Q2), X1.3 (2)
unnamed: D1.4 (G), R2.1
unnamed: D1.3 (B), R3.1
unnamed: C4.1, U1.45 (PD7/XOSC32K_Q2), X2.B (2)
unnamed: R6.2, U3.9 (VBACKUP)
unnamed: C17.1, C18.1, U1.32 (DCOUPL2), U1.56 (DCOUPL1)
unnamed: R5.2, U3.1 (CLKOE)
RF_N: B1.3 (BAL_N), U1.38 (RF_N)
RF_P: B1.4 (BAL_P), U1.37 (RF_P)
RTC_CE: U1.54 (PB1), U3.8 (CE)
SPI_MISO: J3.14, J3.14B (14), U1.5 (PB0), U2.2 (SO), U3.5 (MISO)
SPI_MOSI: J3.15, J3.15B (15), U1.6 (PC7), U2.5 (SI), U3.10 (MOSI)
SPI_SCK: J3.16, J3.16B (16), U1.7 (PC6), U2.6 (SCK), U3.4 (SCL)
TCK: J3.4, J3.4B (4), U1.47 (JTAG_TCK)
TDO: J3.5, J3.5B (5), U1.48 (PB7/JTAG-TDO)
TMS: J3.3, J3.3B (3), U1.46 (JTAG_TMS)
UNUSED1: J3.2, J3.2B (2)
USB_N: J3.12, J3.12B (12), U1.3 (USB_N)
USB_P: J3.11, J3.11B (11), U1.2 (USB_P)
VCC: C5.1, C7.1, C8.1, C9.1, C10.1, C11.1, C12.1, C13.1, C14.1, C15.1, C16.1, D1.1 (VDD), J3.1, J3.1B (1), U1.10 (DVDD), U1.15 (DVDD), U1.24 (DVDD), U1.33 (AVDD), U1.36 (AVDD), U1.39 (AVDD), U1.40 (AVDD), U1.41 (AVDD), U1.43 (AVDD_GUARD), U1.55 (DVDD), U2.8 (VDD), U3.2 (VCC); also elsewhere on the board

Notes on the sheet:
PIN10
PIN15
PIN24
PIN55
PIN33
PIN36
PIN40
PIN43

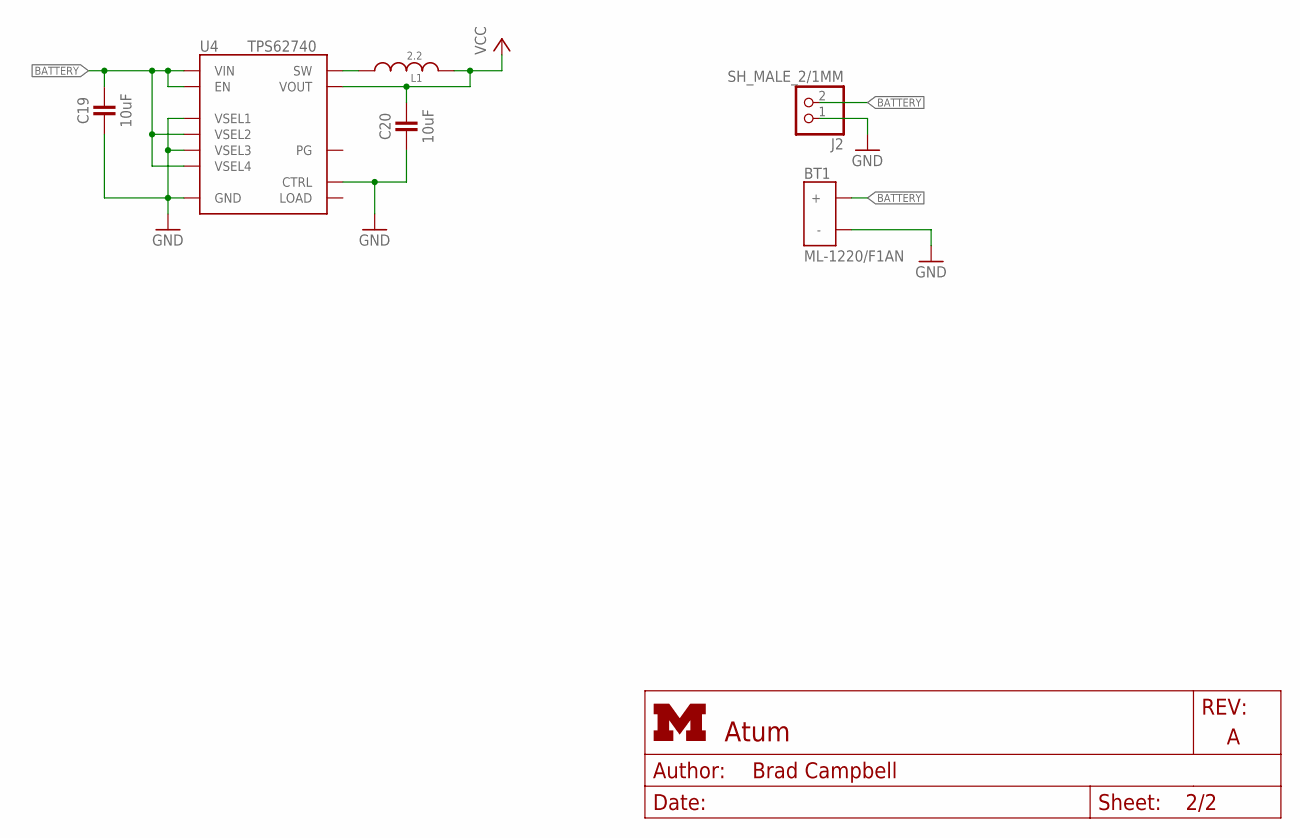
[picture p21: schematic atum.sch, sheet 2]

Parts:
BT1: ML-1220/F1AN; ML-1220/F1BN
C19, C20: 10uF; 0603_CAP; DIGIKEY 490-7316-1-ND
J2: SH_MALE_2/1MM; SH-1X2/1MM
L1: 2.2; MIPSZ201D
U4: TPS62740; R-PWSON-12

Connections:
BATTERY: BT1.POS (+), C19.1, J2.2, U4.1 (VIN), U4.8 (VSEL4), U4.10 (VSEL2), U4.12 (EN); also elsewhere on the board
GND: BT1.NEG (-), C19.2, C20.2, J2.1, U4.3 (GND), U4.4 (CTRL), U4.9 (VSEL3), U4.11 (VSEL1), U4.NC (GND); also elsewhere on the board
unnamed: L1.1, U4.2 (SW)
VCC: C20.1, L1.2, U4.5 (VOUT); also elsewhere on the board

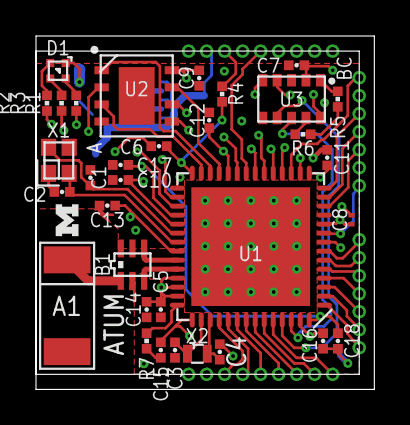
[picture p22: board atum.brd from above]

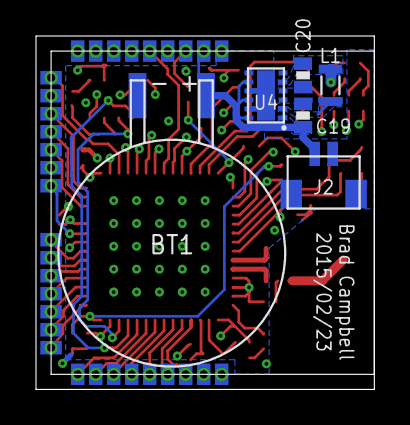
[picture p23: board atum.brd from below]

Board: 4 copper layers, 18.8 x 19.6 mm, 41 parts (6 on the bottom side), 56 nets.

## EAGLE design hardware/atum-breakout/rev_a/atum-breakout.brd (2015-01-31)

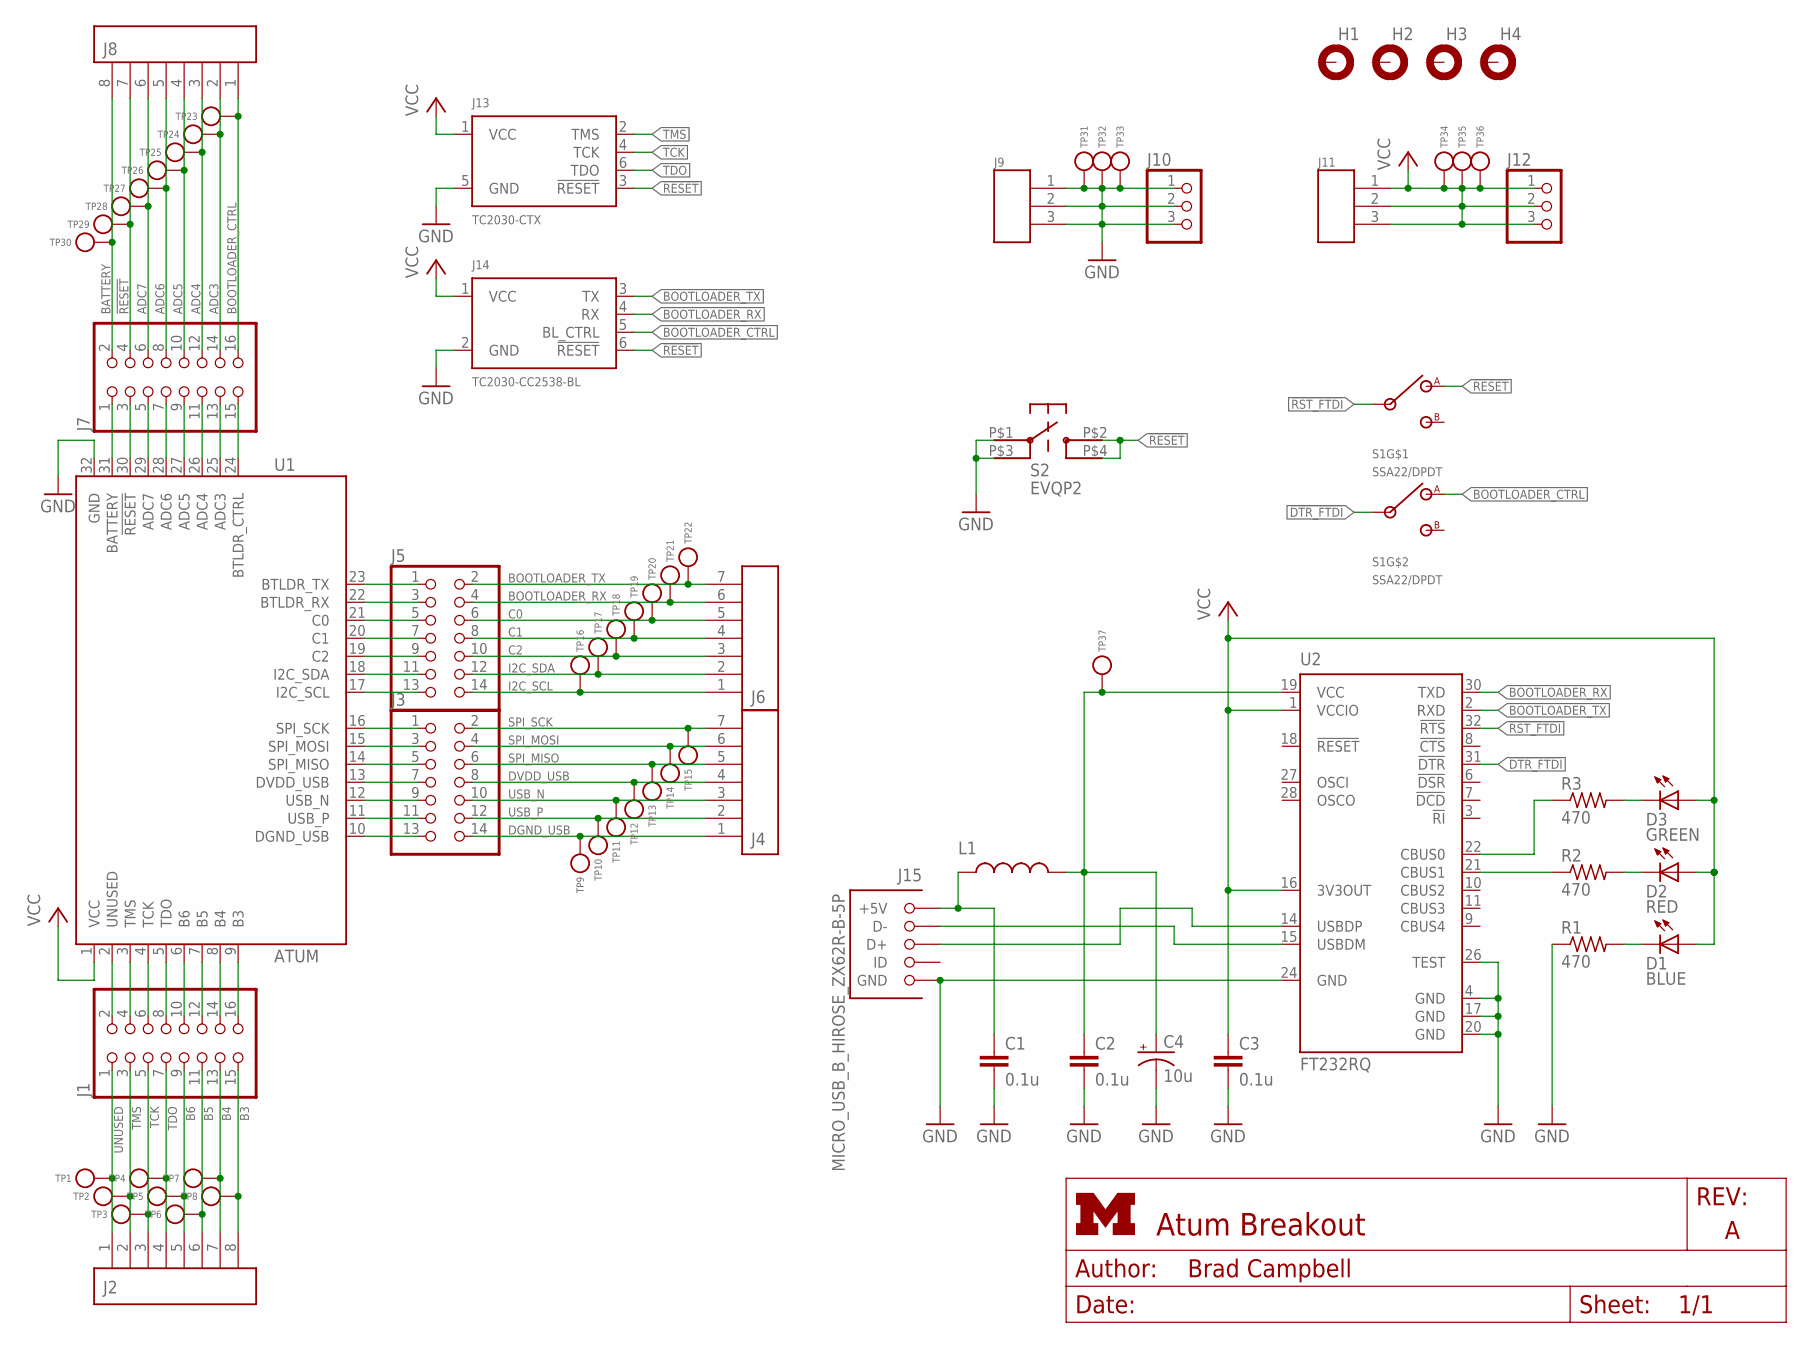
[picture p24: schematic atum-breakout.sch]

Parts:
C1, C2, C3: 0.1u; C0603; DIGIKEY 445-1316-1-ND
C4: 10u; EIA3216; DIGIKEY 478-1655-1-ND
D1: BLUE; LED-0603
D2: RED; LED-0603
D3: GREEN; LED-0603
H1, H2, H3, H4: MOUNT-PAD-ROUND3.2; 3,2-PAD
J1, J7: PINHD-2X8; 2X08; DIGIKEY 609-3364-ND
J2, J8: SCREW-TERMINAL_8_0.100; CONN_BLOCK_8
J3, J5: PINHD-2X7; 2X07; DIGIKEY 609-3491-ND
J4, J6: SCREW-TERMINAL_7_0.100; CONN_BLOCK_7
J9, J11: SCREW-TERMINAL_3_0.100; CONN_BLOCK_3
J10, J12: PINHD-1X3; 1X03
J13: TC2030-CTX; TC2030-IDC
J14: TC2030-CC2538-BL; TC2030-IDC
J15: MICRO_USB_B_HIROSE_ZX62R-B-5P; USB_MICRO_B-HIROSE-ZX62R-B-5P; MOUSER 798-ZX62R-B-5P
L1: INDUCTOR0603; 0603; DIGIKEY 240-2373-1-ND
R1, R2, R3: 470; R0603
S1: SSA22/DPDT; DIGIKEY 450-1604-ND
S2: EVQP2; DIGIKEY P11084SCT-ND
TP1, TP2, TP3, TP4, TP5, TP6, TP7, TP8, TP9, TP10, TP11, TP12, TP13, TP14, TP15, TP16, TP17, TP18, TP19, TP20, TP21, TP22, TP23, TP24, TP25, TP26, TP27, TP28, TP29, TP30, TP31, TP32, TP33, TP34, TP35, TP36, TP37: TEST_POINT_0.040IN; TESTPOINT_0.040IN
U1: ATUM
U2: FT232RQ; QFN32; DIGIKEY 768-1008-1-ND

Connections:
!DTR_FTDI: S1.COM2 (2), U2.31 (!DTR)
!RESET: J7.3, J7.4, J8.7, J13.3 (!RESET), J14.6 (!RESET), S1.A1 (1), S2.P$2, S2.P$4, TP29.TESTPOINT, U1.30 (!RESET)
!RST_FTDI: S1.COM1 (2), U2.32 (!RTS)
ADC3: J7.13, J7.14, J8.2, TP24.TESTPOINT, U1.25 (ADC3)
ADC4: J7.11, J7.12, J8.3, TP25.TESTPOINT, U1.26 (ADC4)
ADC5: J7.9, J7.10, J8.4, TP26.TESTPOINT, U1.27 (ADC5)
ADC6: J7.7, J7.8, J8.5, TP27.TESTPOINT, U1.28 (ADC6)
ADC7: J7.5, J7.6, J8.6, TP28.TESTPOINT, U1.29 (ADC7)
B3: J1.15, J1.16, J2.8, TP8.TESTPOINT, U1.9 (B3)
B4: J1.13, J1.14, J2.7, TP7.TESTPOINT, U1.8 (B4)
B5: J1.11, J1.12, J2.6, TP6.TESTPOINT, U1.7 (B5)
B6: J1.9, J1.10, J2.5, TP5.TESTPOINT, U1.6 (B6)
BATTERY: J7.1, J7.2, J8.8, TP30.TESTPOINT, U1.31 (BATTERY)
BOOTLOADER_CTRL: J7.15, J7.16, J8.1, J14.5 (BL_CTRL), S1.A2 (1), TP23.TESTPOINT, U1.24 (BTLDR_CTRL)
BOOTLOADER_RX: J5.3, J5.4, J6.6, J14.4 (RX), TP21.TESTPOINT, U1.22 (BTLDR_RX), U2.30 (TXD)
BOOTLOADER_TX: J5.1, J5.2, J6.7, J14.3 (TX), TP22.TESTPOINT, U1.23 (BTLDR_TX), U2.2 (RXD)
C0: J5.5, J5.6, J6.5, TP20.TESTPOINT, U1.21 (C0)
C1: J5.7, J5.8, J6.4, TP19.TESTPOINT, U1.20 (C1)
C2: J5.9, J5.10, J6.3, TP18.TESTPOINT, U1.19 (C2)
DGND_USB: J3.13, J3.14, J4.1, TP9.TESTPOINT, U1.10 (DGND_USB)
DVDD_USB: J3.7, J3.8, J4.4, TP12.TESTPOINT, U1.13 (DVDD_USB)
GND: C1.2, C2.2, C3.2, C4.C (-), J9.1, J9.2, J9.3, J10.1, J10.2, J10.3, J13.5 (GND), J14.2 (GND), J15.5 (GND), R1.1, S2.P$1, S2.P$3, TP31.TESTPOINT, TP32.TESTPOINT, TP33.TESTPOINT, U1.32 (GND), U2.4 (GND), U2.17 (GND), U2.20 (GND), U2.24 (GND), U2.26 (TEST)
I2C_SCL: J5.13, J5.14, J6.1, TP16.TESTPOINT, U1.17 (I2C_SCL)
I2C_SDA: J5.11, J5.12, J6.2, TP17.TESTPOINT, U1.18 (I2C_SDA)
unnamed: R3.1, U2.22 (CBUS0)
unnamed: D2.C, R2.2
unnamed: J15.2 (D-), U2.15 (USBDM)
unnamed: J15.3 (D+), U2.14 (USBDP)
unnamed: R2.1, U2.21 (CBUS1)
unnamed: C2.1, C4.A (+), L1.2, TP37.TESTPOINT, U2.19 (VCC)
unnamed: D3.C, R3.2
unnamed: D1.C, R1.2
SPI_MISO: J3.5, J3.6, J4.5, TP13.TESTPOINT, U1.14 (SPI_MISO)
SPI_MOSI: J3.3, J3.4, J4.6, TP14.TESTPOINT, U1.15 (SPI_MOSI)
SPI_SCK: J3.1, J3.2, J4.7, TP15.TESTPOINT, U1.16 (SPI_SCK)
TCK: J1.5, J1.6, J2.3, J13.4 (TCK), TP3.TESTPOINT, U1.4 (TCK)
TDO: J1.7, J1.8, J2.4, J13.6 (TDO), TP4.TESTPOINT, U1.5 (TDO)
TMS: J1.3, J1.4, J2.2, J13.2 (TMS), TP2.TESTPOINT, U1.3 (TMS)
UNUSED: J1.1, J1.2, J2.1, TP1.TESTPOINT, U1.2 (UNUSED)
USB5V: C1.1, J15.1 (+5V), L1.1
USB_N: J3.9, J3.10, J4.3, TP11.TESTPOINT, U1.12 (USB_N)
USB_P: J3.11, J3.12, J4.2, TP10.TESTPOINT, U1.11 (USB_P)
VCC: C3.1, D1.A, D2.A, D3.A, J11.1, J11.2, J11.3, J12.1, J12.2, J12.3, J13.1 (VCC), J14.1 (VCC), TP34.TESTPOINT, TP35.TESTPOINT, TP36.TESTPOINT, U1.1 (VCC), U2.1 (VCCIO), U2.16 (3V3OUT)

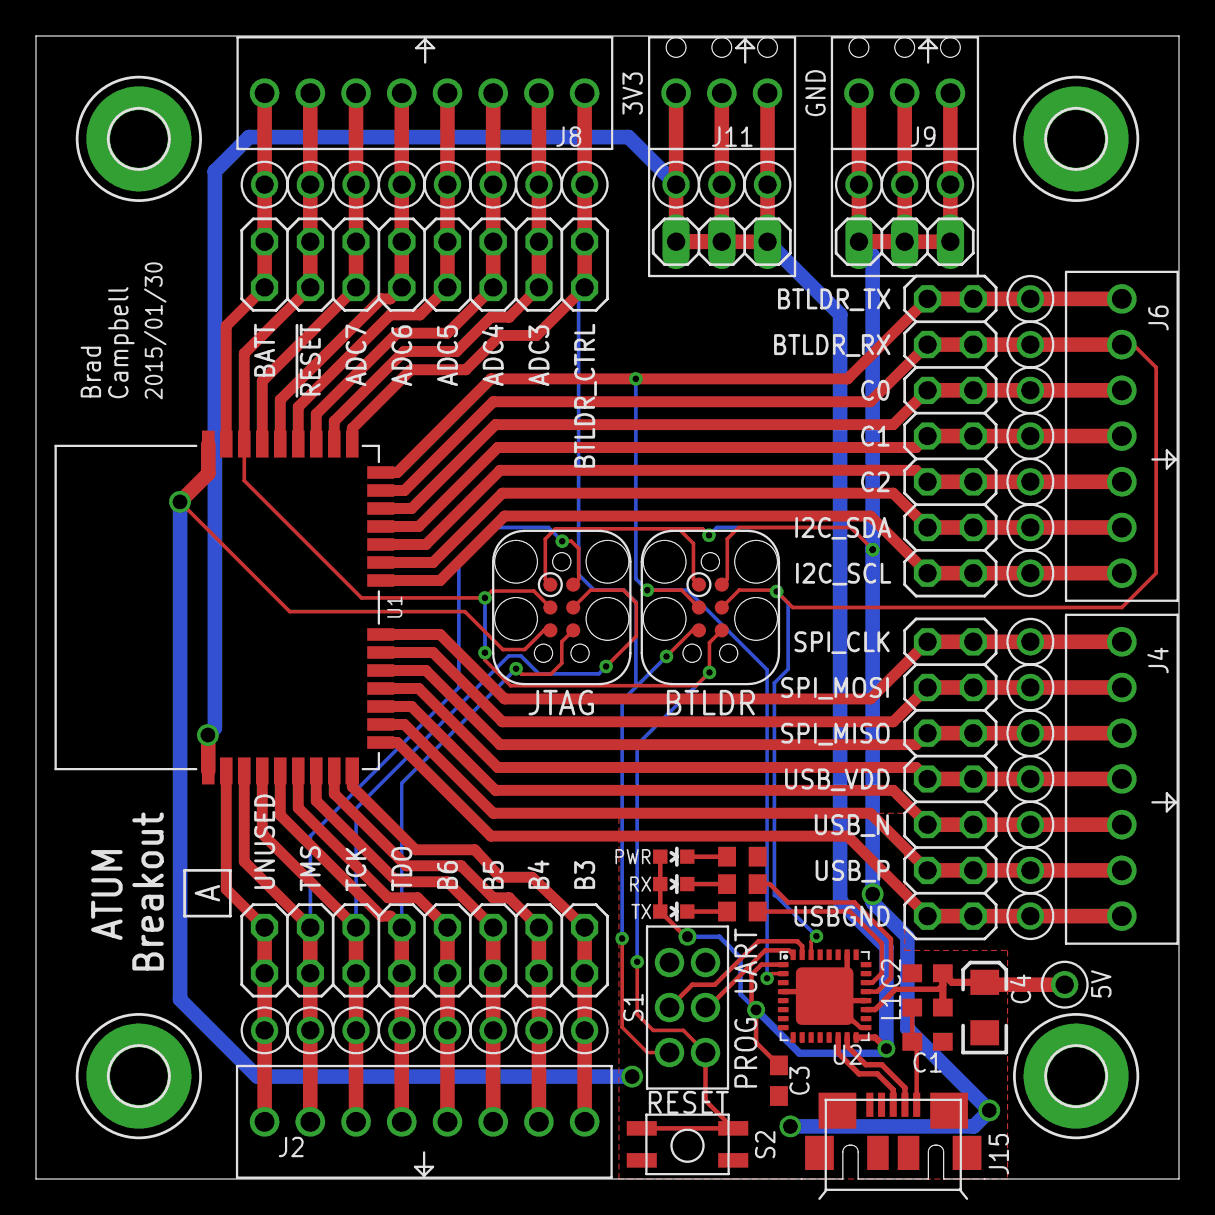
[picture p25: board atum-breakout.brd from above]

Board: 2 copper layers, 63.5 x 63.5 mm, 71 parts (0 on the bottom side), 43 nets.

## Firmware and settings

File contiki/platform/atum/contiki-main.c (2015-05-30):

/**
 * \addtogroup platform
 * @{
 *
 * \defgroup atum The atum sensor mote module.
 * @{
 *
 * \file
 *   Main module for the atum platform
 */
/*---------------------------------------------------------------------------*/
#include "contiki.h"
#include "dev/leds.h"
#include "dev/sys-ctrl.h"
#include "dev/scb.h"
#include "dev/nvic.h"
#include "dev/uart.h"
#include "dev/watchdog.h"
#include "dev/ioc.h"
#include "dev/button-sensor.h"
#include "dev/serial-line.h"
#include "dev/slip.h"
#include "dev/cc2538-rf.h"
#include "dev/udma.h"
#include "usb/usb-serial.h"
#include "lib/random.h"
#include "net/netstack.h"
#include "net/queuebuf.h"
#include "net/ip/tcpip.h"
#include "net/ip/uip.h"
#include "net/mac/frame802154.h"
#include "cpu.h"
#include "reg.h"
#include "ieee-addr.h"
#include "lpm.h"
#include "spi.h"
#include "fm25l04b.h"
#include "rv3049.h"

#include <stdint.h>
#include <string.h>
#include <stdio.h>
/*---------------------------------------------------------------------------*/
#if STARTUP_CONF_VERBOSE
#define PRINTF(...) printf(__VA_ARGS__)
#else
#define PRINTF(...)
#endif

#if UART_CONF_ENABLE
#define PUTS(s) puts(s)
#else
#define PUTS(s)
#endif
/*---------------------------------------------------------------------------*/
static void
set_rf_params(void)
{
    uint16_t short_addr;
    uint8_t ext_addr[8];

    ieee_addr_cpy_to(ext_addr, 8);

    short_addr = ext_addr[7];
    short_addr |= ext_addr[6] << 8;

    /* Populate linkaddr_node_addr. Maintain endianness */
    memcpy(&linkaddr_node_addr, &ext_addr[8 - LINKADDR_SIZE], LINKADDR_SIZE);

#if STARTUP_CONF_VERBOSE
    {
        int i;
        printf("Rime configured with address ");
        for(i = 0; i < LINKADDR_SIZE - 1; i++) {
            printf("%02x:", linkaddr_node_addr.u8[i]);
        }
        printf("%02x\n", linkaddr_node_addr.u8[i]);
    }
#endif

    NETSTACK_RADIO.set_value(RADIO_PARAM_PAN_ID, IEEE802154_PANID);
    NETSTACK_RADIO.set_value(RADIO_PARAM_16BIT_ADDR, short_addr);
    NETSTACK_RADIO.set_value(RADIO_PARAM_CHANNEL, CC2538_RF_CHANNEL);
    NETSTACK_RADIO.set_object(RADIO_PARAM_64BIT_ADDR, ext_addr, 8);
}
/*---------------------------------------------------------------------------*/
/**
 * \brief Main routine for the cc2538dk platform
 */
int
main(void)
{

  nvic_init();
  ioc_init();
  sys_ctrl_init();
  clock_init();
  lpm_init();
  rtimer_init();
  gpio_init();

  leds_init();

  process_init();

#if WATCHDOG_ATUM_ENABLE
  watchdog_init();
#endif
  //button_sensor_init();
  spi_init();
  fm25l04b_init();
  rv3049_init();

  /*
   * Character I/O Initialization.
   * When the UART receives a character it will call serial_line_input_byte to
   * notify the core. The same applies for the USB driver.
   *
   * If slip-arch is also linked in afterwards (e.g. if we are a border router)
   * it will overwrite one of the two peripheral input callbacks. Characters
   * received over the relevant peripheral will be handled by
   * slip_input_byte instead
   */
#if UART_CONF_ENABLE
  uart_init(0);
  uart_init(1);
  uart_set_input(SERIAL_LINE_CONF_UART, serial_line_input_byte);
#endif

#if USB_SERIAL_CONF_ENABLE
  usb_serial_init();
  usb_serial_set_input(serial_line_input_byte);
#endif

  serial_line_init();

  INTERRUPTS_ENABLE();

  PUTS(CONTIKI_VERSION_STRING);
  PUTS(BOARD_STRING);

  PRINTF(" Net: ");
  PRINTF("%s\n", NETSTACK_NETWORK.name);
  PRINTF(" MAC: ");
  PRINTF("%s\n", NETSTACK_MAC.name);
  PRINTF(" RDC: ");
  PRINTF("%s\n", NETSTACK_RDC.name);

  /* Initialise the H/W RNG engine. */
  random_init(0);

  udma_init();

  process_start(&etimer_process, NULL);
  ctimer_init();

  set_rf_params();
  netstack_init();

#if NETSTACK_CONF_WITH_IPV6
  memcpy(&uip_lladdr.addr, &linkaddr_node_addr, sizeof(uip_lladdr.addr));
  queuebuf_init();
  process_start(&tcpip_process, NULL);
#endif /* NETSTACK_CONF_WITH_IPV6 */

  //process_start(&sensors_process, NULL);

  energest_init();
  ENERGEST_ON(ENERGEST_TYPE_CPU);

  autostart_start(autostart_processes);

#if WATCHDOG_ATUM_ENABLE
  watchdog_start();
#endif

  while(1) {
    uint8_t r;
    do {
#if WATCHDOG_ATUM_ENABLE
      /* Reset watchdog and handle polls and events */
      watchdog_periodic();
#endif

      r = process_run();
    } while(r > 0);

    /* We have serviced all pending events. Enter a Low-Power mode. */
    lpm_enter();
  }
}
/*---------------------------------------------------------------------------*/

/**
 * @}
 * @}
 */

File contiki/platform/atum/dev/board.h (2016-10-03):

/*
 * Copyright (c) 2012, Texas Instruments Incorporated - http://www.ti.com/
 * All rights reserved.
 *
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
 * 3. Neither the name of the copyright holder nor the names of its
 *    contributors may be used to endorse or promote products derived
 *    from this software without specific prior written permission.
 *
 * THIS SOFTWARE IS PROVIDED BY THE COPYRIGHT HOLDERS AND CONTRIBUTORS
 * ``AS IS'' AND ANY EXPRESS OR IMPLIED WARRANTIES, INCLUDING, BUT NOT
 * LIMITED TO, THE IMPLIED WARRANTIES OF MERCHANTABILITY AND FITNESS
 * FOR A PARTICULAR PURPOSE ARE DISCLAIMED.  IN NO EVENT SHALL THE
 * COPYRIGHT HOLDER OR CONTRIBUTORS BE LIABLE FOR ANY DIRECT, INDIRECT,
 * INCIDENTAL, SPECIAL, EXEMPLARY, OR CONSEQUENTIAL DAMAGES
 * (INCLUDING, BUT NOT LIMITED TO, PROCUREMENT OF SUBSTITUTE GOODS OR
 * SERVICES; LOSS OF USE, DATA, OR PROFITS; OR BUSINESS INTERRUPTION)
 * HOWEVER CAUSED AND ON ANY THEORY OF LIABILITY, WHETHER IN CONTRACT,
 * STRICT LIABILITY, OR TORT (INCLUDING NEGLIGENCE OR OTHERWISE)
 * ARISING IN ANY WAY OUT OF THE USE OF THIS SOFTWARE, EVEN IF ADVISED
 * OF THE POSSIBILITY OF SUCH DAMAGE.
 */
/** \addtogroup cc2538
 * @{
 *
 * \defgroup cc2538-smartrf SmartRF06EB Peripherals
 *
 * Defines related to the SmartRF06EB
 *
 * This file provides connectivity information on LEDs, Buttons, UART and
 * other SmartRF peripherals
 *
 * Notably, PC0 is used to drive LED1 as well as the USB D+ pullup. Therefore
 * when USB is enabled, LED1 can not be driven by firmware.
 *
 * This file can be used as the basis to configure other platforms using the
 * cc2538 SoC.
 * @{
 *
 * \file
 * Header file with definitions related to the I/O connections on the TI
 * SmartRF06EB
 *
 * \note   Do not include this file directly. It gets included by contiki-conf
 *         after all relevant directives have been set.
 */
#ifndef BOARD_H_
#define BOARD_H_

#include "dev/gpio.h"
#include "dev/nvic.h"
/*---------------------------------------------------------------------------*/
/** \name SmartRF LED configuration
 *
 * LEDs on the SmartRF06 (EB and BB) are connected as follows:
 * - LED1 (Red)    -> PC0
 * - LED2 (Yellow) -> PC1
 * - LED3 (Green)  -> PC2
 * - LED4 (Orange) -> PC3
 *
 * LED1 shares the same pin with the USB pullup
 * @{
 */
/*---------------------------------------------------------------------------*/
/* Some files include leds.h before us, so we need to get rid of defaults in
 * leds.h before we provide correct definitions */
#undef LEDS_GREEN
#undef LEDS_BLUE
#undef LEDS_RED
#undef LEDS_CONF_ALL

#define LEDS_BLUE                16 /**< PD4 */
#define LEDS_RED                 8  /**< PD3 */
#define LEDS_GREEN               32 /**< PD5 */
#define LEDS_CONF_ALL            56

/* Notify various examples that we have LEDs */
#define PLATFORM_HAS_LEDS        1

#define LED_BLUE_BASE            GPIO_D_BASE
#define LED_RED_BASE             GPIO_D_BASE
#define LED_GREEN_BASE           GPIO_D_BASE
#define LED_BLUE_MASK            GPIO_PIN_MASK(4)
#define LED_RED_MASK             GPIO_PIN_MASK(3)
#define LED_GREEN_MASK           GPIO_PIN_MASK(5)
/** @} */
/*---------------------------------------------------------------------------*/
/** \name USB configuration
 *
 * The USB pullup is driven by PC0 and is shared with LED1
 */
#define USB_PULLUP_PORT          GPIO_C_NUM
#define USB_PULLUP_PIN           0
/** @} */
/*---------------------------------------------------------------------------*/
/** \name UART configuration
 *
 * On the SmartRF06EB, the UART (XDS back channel) is connected to the
 * following ports/pins
 * - RX:  PA0
 * - TX:  PA1
 * - CTS: PB0 (Can only be used with UART1)
 * - RTS: PD3 (Can only be used with UART1)
 *
 * We configure the port to use UART0. To use UART1, replace UART0_* with
 * UART1_* below.
 * @{
 */
#define UART0_RX_PORT            GPIO_A_NUM
#define UART0_RX_PIN             0

#define UART0_TX_PORT            GPIO_A_NUM
#define UART0_TX_PIN             1
// unused uart1
#define UART1_CTS_PORT           GPIO_C_NUM
#define UART1_CTS_PIN            1

#define UART1_RTS_PORT           GPIO_C_NUM
#define UART1_RTS_PIN            2
/** @} */


#define DW1000_CS_N_PORT_NUM   GPIO_C_NUM
#define DW1000_CS_N_PIN        0
#define DW1000_IRQ_PORT_NUM    GPIO_C_NUM
#define DW1000_IRQ_PIN         1
#define DW1000_RST_N_PORT_NUM  GPIO_B_NUM
#define DW1000_RST_N_PIN       3
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

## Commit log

2014-04-28 renamed myth to atum
    [atum.brd, atum.sch]
2014-04-28 shipped atum
    [atum.sch]
2014-05-08 updated silkscreen and names
    - renumbered parts
    - made silkscreen names for assembly
    [atum.brd, atum.sch]
2014-05-08 added bom
    [atum_bom.xlsx]
2014-05-08 new publish files for atum
    [atum_bom.csv]
2014-05-28 add fram driver for atum/contiki
2014-05-28 first pass of porting rv3049 driver from tinyos
2014-05-31 forgot about the led
2014-06-03 updated rtc driver
2014-06-03 added rtc driver to be compiled every time
    needs updated rtc init values
2014-06-04 created atum breakout board
    [atum-breakout.brd, atum-breakout.sch]
2014-06-04 updated part labels
    [atum-breakout.brd, atum-breakout.sch]
2014-06-05 atum breakout bom
    [atum-breakout.brd, atum-breakout.sch, atum-breakout_bom.xlsx]
2014-06-05 updated breakout bom
    [atum-breakout_bom.xlsx]
2014-06-05 added rev letter and updated date on silkscreen
    [atum-breakout.brd]
2014-06-05 added publish files for atum-breakout
    [atum-breakout_bom.csv]
2014-06-08 trying to improve castellations
    [atum.brd, atum.sch]
2014-08-02 smaller vias
    [atum.brd, atum.sch]
2014-08-30 new atum a
    designed for advanced circuits default stack
    [atum.brd]
2014-08-30 adc test for airflow sensor
2015-01-31 updated atum breakout
    [atum-breakout.brd, atum-breakout.sch]
2015-02-23 made panel for atum
    added fab notes
    [atum.brd]
2015-03-01 get all 3 packets with dw1000
    doesn't do range yet, however...
    [board.h, project-conf.h]
2015-03-01 added support for pannelizing atum
    [atum.brd]
2015-03-22 add pricing estimate
    [atum_bom_pricing.xlsx]
2015-03-29 coap leds for setting leds
2015-05-15 coap leds changes
2015-11-23 fix rtc test to compile with new contiki
    they fixed their led API problem
2016-06-17 add magnetic mount
    [atum_breakout_magnet_base.SLDPRT, atum_breakout_magnet_base_v1.STL]
2016-10-03 add i2c pins to board.h

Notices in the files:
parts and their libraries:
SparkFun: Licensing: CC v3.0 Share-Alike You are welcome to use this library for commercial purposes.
